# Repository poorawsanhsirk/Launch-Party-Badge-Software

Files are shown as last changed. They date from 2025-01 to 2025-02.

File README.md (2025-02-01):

# Firefly Badge Software Repository

## Overview
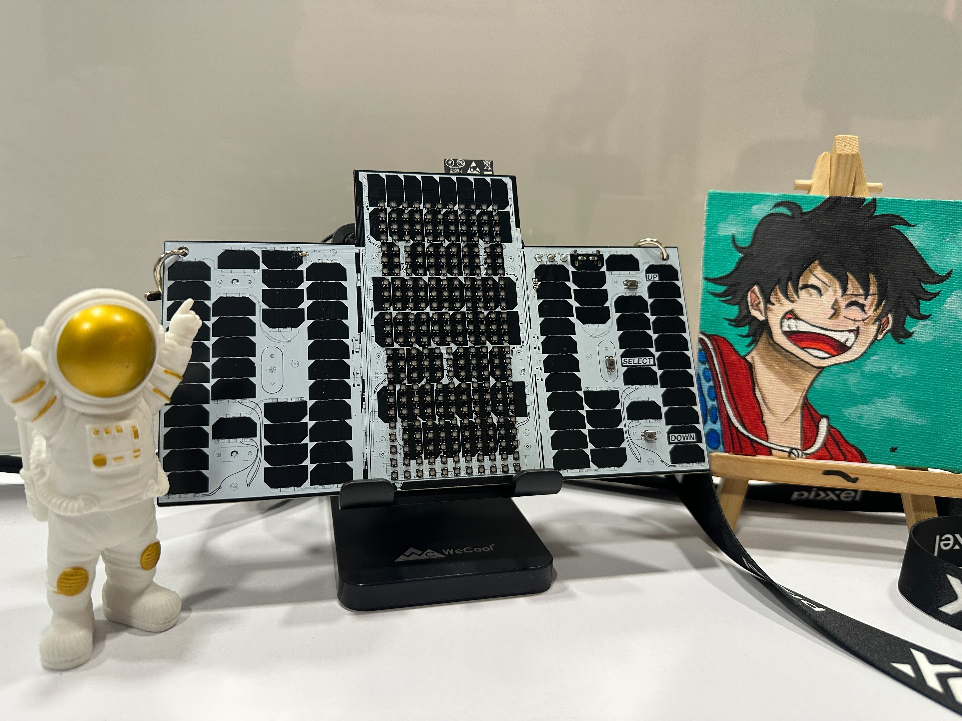
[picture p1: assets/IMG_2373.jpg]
Badge_Picture
  
This Firefly Badge features an **11x24 LED Matrix** that provides a visual representation of various countdown timers for tracking Launch and Injection Time. The matrix uses color-coded animations and progress indicators to signal important milestones.  
The software provided in the repository is meant for the Launch Viewing Party being held at Pixxel Space India Office in HBR Layout, Bangalore.  
The badge has been built to act as a souvenir and memento to celebrate the people, their efforts and the countless sleepless nights that went into making Firefly a reality.

**We highly recommend tinkering around with this badge later**. 
It is basically an ESP32-C3 Devkit with an LED Matrix after you leave the party. Feel free to reach out if you need any help getting started. Looking forward to what people end up building with this.
Psst...Psst, you can build a Firefly Themed Table Clock as a starter project.

---
## Instructions for Programming and developing your own code

1. **Install Arduino IDE on your local machine**
   - Link
2. **Clone this repository on your local machine**
   - If you have Git installed, you can just used `git clone <url>`
   - If you dont have Git install, consider installing Git, it will change your life.
   - If you are still hell-bent on not changing your life, you could just download this repo as a .zip folder and extract it
3. **Navigate to Relevant Folder**
   - After the launch party, the code in release/Version2_LowPower will not work as it requires a connection to Office WiFi and a server to ping.
   - However, you can flash your own code and make the ESP32 do whatever you want. You could re-use the Driver I have written for the LED Matrix Drivers in order to display something
   - If you just want the LEDs to light up and do some fun animations, you could try programming your badge with the `release/Demonstration' firmware
4. Program your badge with the firmware that you want (steps below assume that you want to program the Demonstration code)
   - Connect your badge to your PC/Laptop using a USB-C Cable. This cable provides both power and data connection to the ESP32.
   - Open Arduino IDE and open the Demonstration.ino file by going to File->Open in the IDE Menubar
   - If this is the first time you have installed Arduino IDE, you will have to install the ESP32 Board drivers. Open Board Manager in Arduino IDE and search for ESP32.
   - After installing relevant drivers, your badge will get recognised by the IDE. Please select ESP32C3-Dev Module as your board type and select the correct COM Port
   - Now you are ready to program the badge. Click on the Upload Button in the Arduino IDE. This will compile and flash your badge with the Demonstration Firmware.
5. The Demonstration Firmware does the following animations
   - Blue Progress Bar to simulate Launch Countdown
   - Green LED Flashing
   - Blue LED Flashing
   - Injection Timer Simulation
   - Injection Intimation Simulation
You could cycle through each animation by pressing and holding the UP Button
---
## Installation & Usage
1. **Power ON the Badge**:
   - Connect the provided 9V Battery to the Battery Connector present on the board.
   - Turn ON the board by flipping the Power Switch to the ON Position.
   - Wait a couple of seconds for the ESP32 to fetch relevant information from an API Endpoint hosted locally in Pixxel Office.
   - The **Launch Timer** should start automatically.
2. **Switch to Injection Timer after launch is done**:
   - Press and hold the **Select** button until the blue flashing animation begins.
   - Release the button to transition.
3. **Monitor Progress**:
   - Observe progress bars and flashing indicators to track the timers. Here's to hoping you don't miss watching the Launch :3
4. In order to conserve power and last through the entire launch schedule, the board displays info for 60 seconds and goes to sleep for 20 seconds. Please don't panic if your display goes OFF for a while
---
## LED Matrix Behavior

### 1. **Launch Timer**
- **Initial State**: When the badge is powered ON:
  - Progress towards the **Launch Time** is displayed vertically on the LED Matrix.
  - Each **blue row** represents a step closer to the launch.
- **1 Minute to Launch**:
  - The entire matrix begins flashing **green** to signal the approaching launch time.
- **Post Launch**:
  - The entire matrix glows green.  
---

### 2. **Transition Animation**
- **Activation**:
  - User presses and holds the **Select** button.
- **Animation**:
  - LED Matrix flashes **blue** to confirm the transition. 
- **Completion**:
  - The badge switches between modes once the user releases the button after the blue flashing begins.
---

### 3. **Injection Timer**
- **Initial Display**:
  - The LED Matrix is divided into 3 sections, each **6 rows high**, to display progress for 3 different timers.
  - Progress towards each **Injection Time** is shown by the number of **blue rows lit** in each section.
- **Below 30 Seconds**:
  - The rows corresponding to the timer with less than 30 seconds start flashing **green**.

---

## Technical Details

### LED Matrix
- **Resolution**: 11 columns x 24 rows. 264 RGB LEDs driven by 4 LP5860 LED Matrix Drivers.
- LED Driver ICs are connected over I2C. VIO_EN and VSYNC are also connected  
### Controller 
- **ESP32-C3-WROOM-02-N4 Module**

### Secret Peripheral
- The PCB has provision for an un-populated component which unlocks a lot more projects that you can do with this badge. Maybe even "Attitude Control" your Firefly :)
### Hardware Design
Refer to the hardware directory for KiCAD Files of the Firefly Badge PCB. The repo contains final schematics, layout, gerbers and BoM. Reach out if you need any clarifications.  

Basically everything you require to make your own Firefly Badge in case you missed out on getting your hands on one from the Launch Event

---

## Troubleshooting
This badge was made in 15 days from when we decided to do it. The software for this was written in 48 hours by an Electronics Engineer with no sleep.  
Excuse the bad coding practices.  
Also, there might be some issues when there are around 200 devices in the wild suddenly with close to zero testing.

---

## Glam Shots
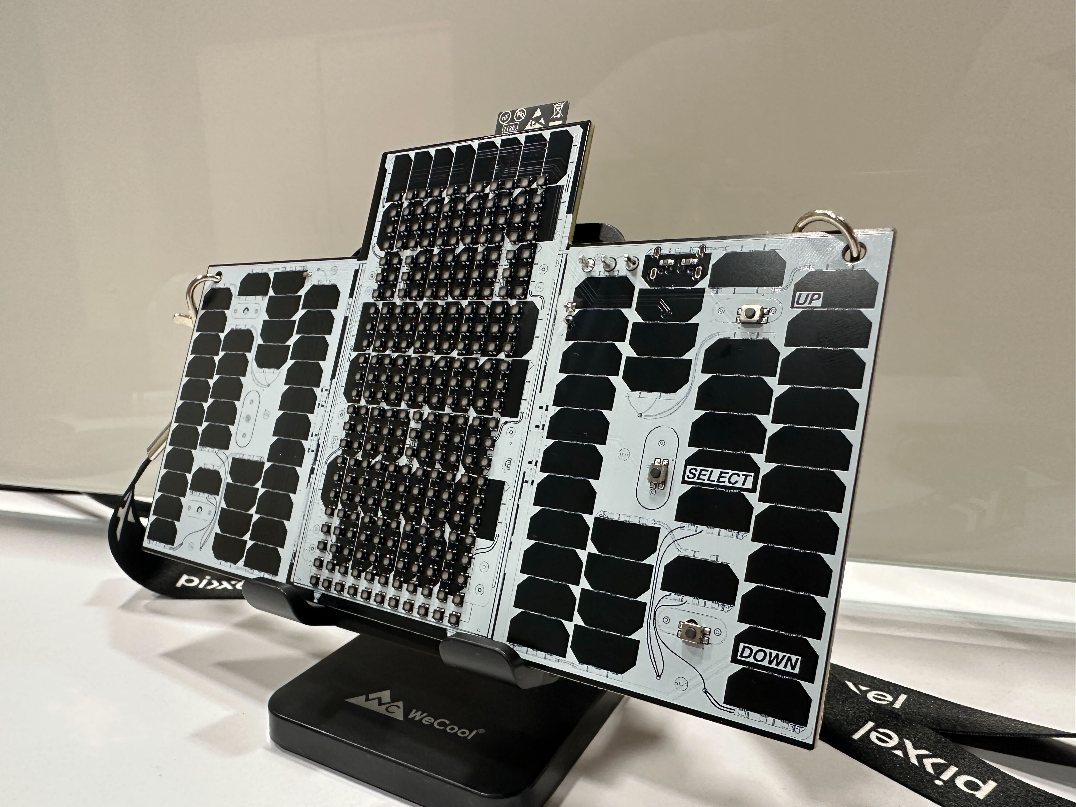
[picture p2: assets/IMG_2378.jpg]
Front

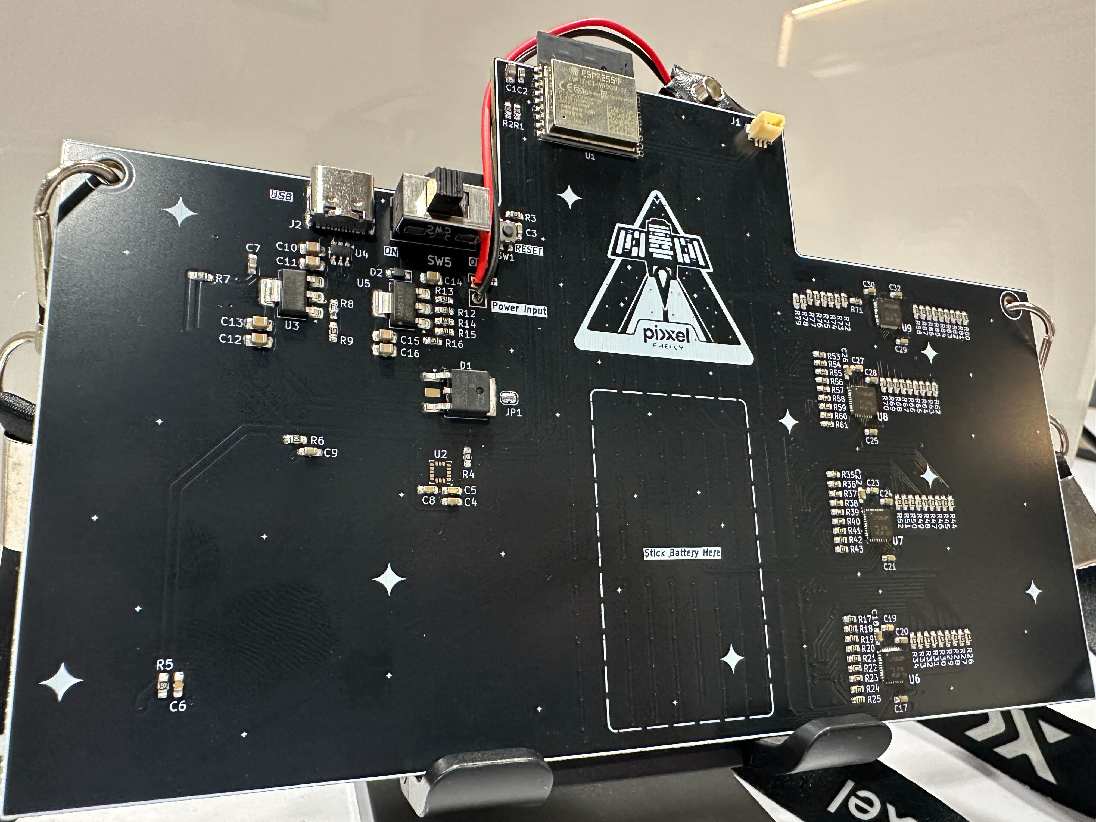
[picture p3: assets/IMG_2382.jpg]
Back

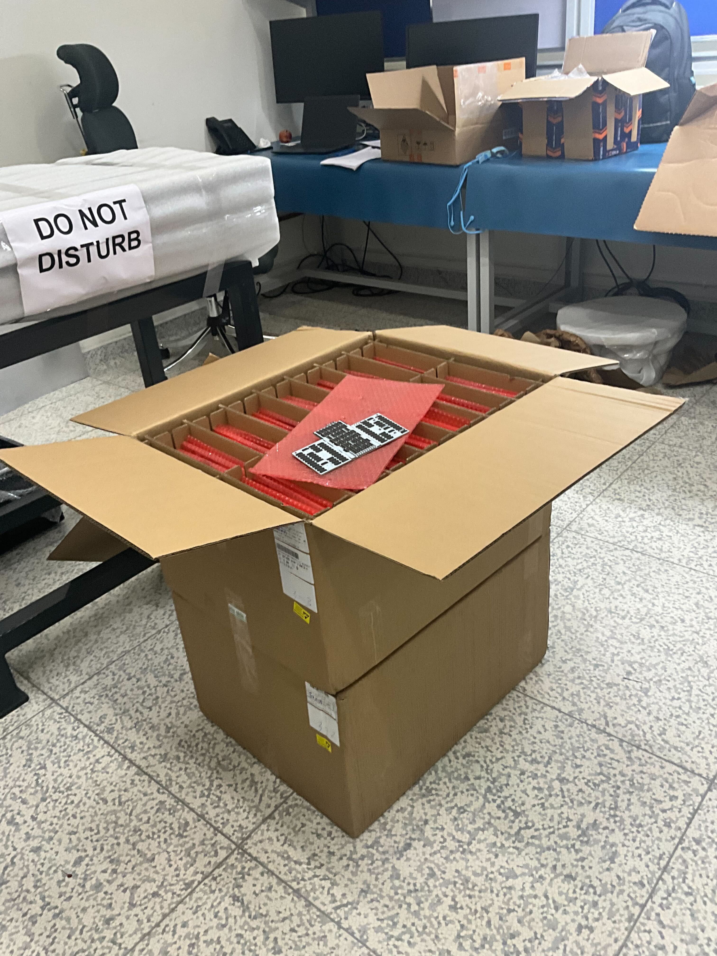
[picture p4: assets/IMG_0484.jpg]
Delivery Box

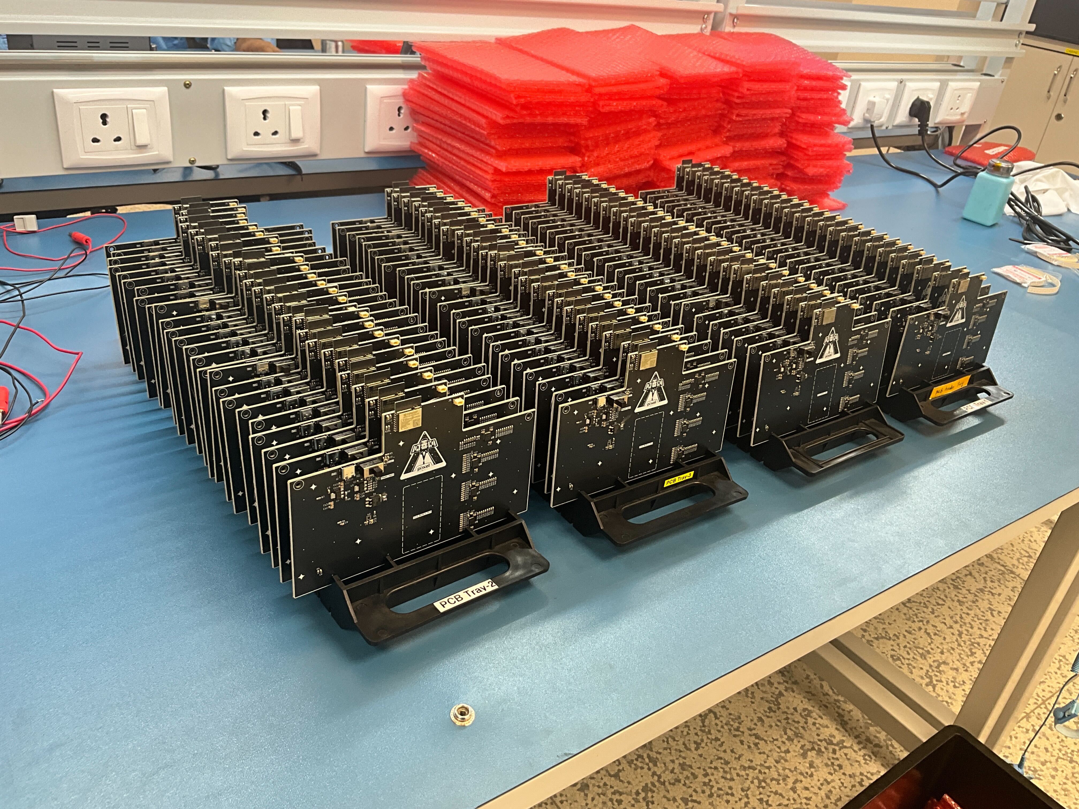
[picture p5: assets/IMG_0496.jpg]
PCB Array

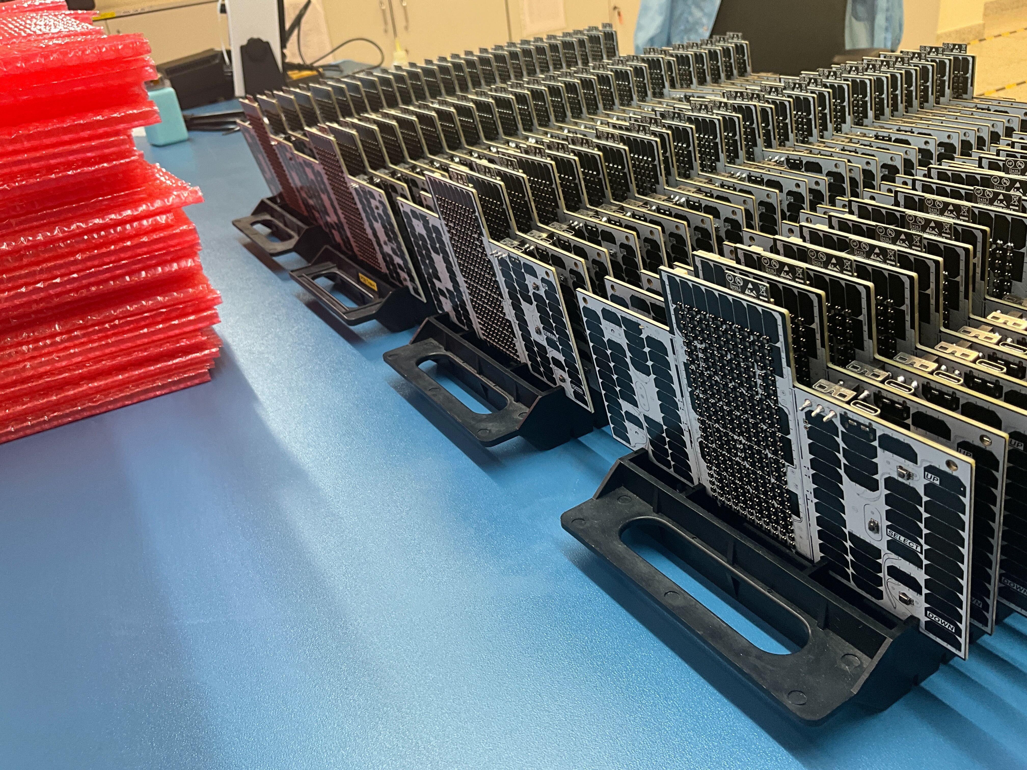
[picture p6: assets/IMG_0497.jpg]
PCB Array1

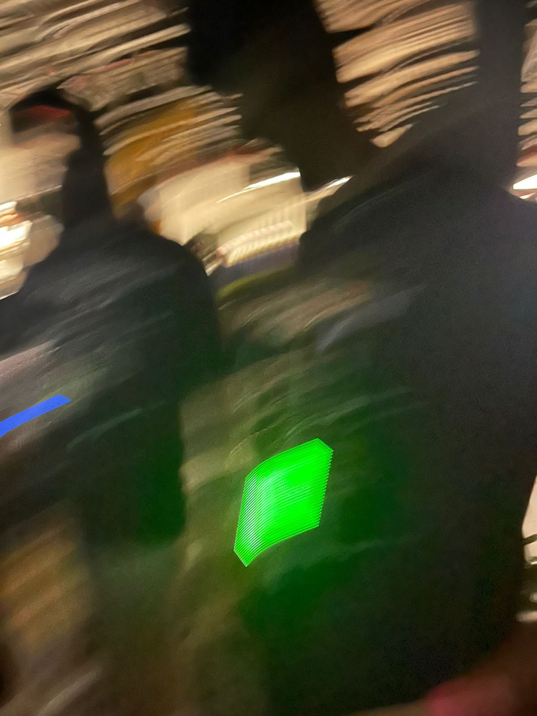
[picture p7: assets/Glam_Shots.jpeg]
Glam Shot

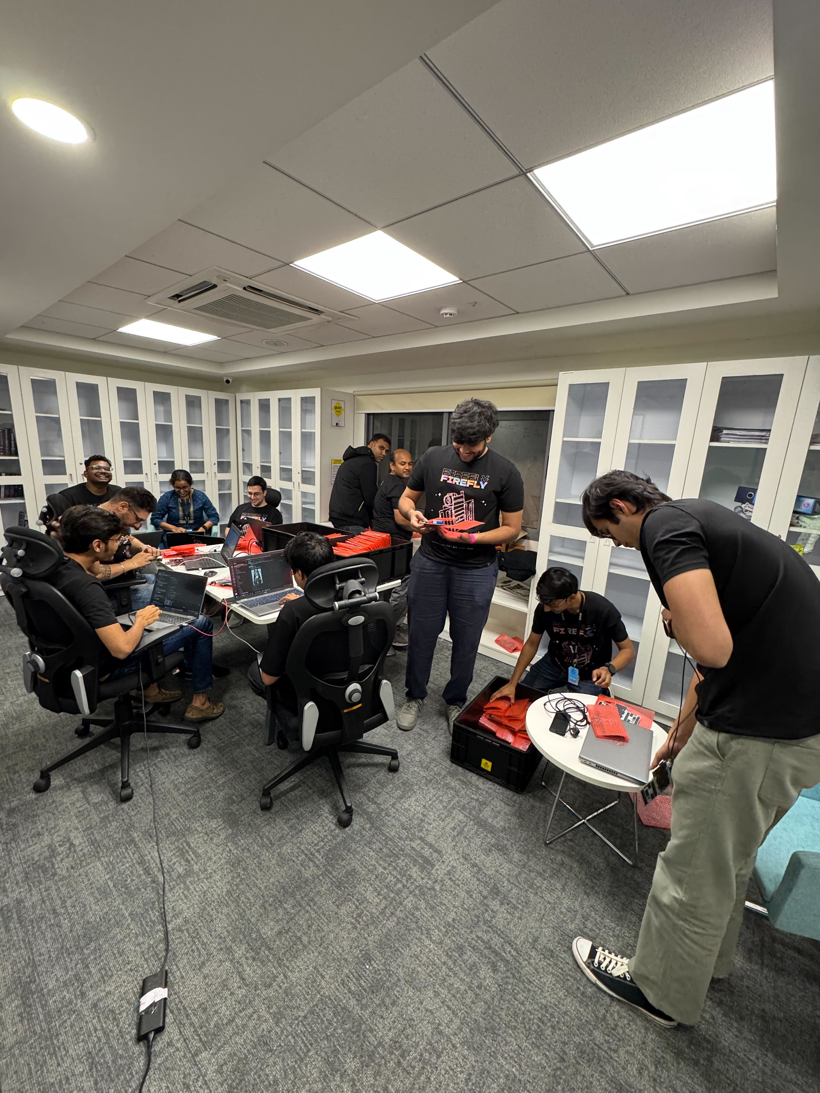
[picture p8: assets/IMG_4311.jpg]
SweatShop Scenes


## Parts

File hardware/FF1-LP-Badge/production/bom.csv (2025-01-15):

Designator | Footprint | Quantity | Value | LCSC Part #
C1, C10, C11, C12, C13, C14, C15, C16 | 0805 | 8 | 10uF_16V_0805
C17, C18, C2, C20, C21, C22, C24, C25, C26, C28, C29, C3, C30, C32, C4, C6, C7, C8, C9 | 0603 | 19 | 1uF_16V_0603
C19, C23, C27, C31, C5 | 0603 | 5 | 1nF_16V_0603
D1 | TO-252-3_TabPin2 | 1 | MBR1045CS | C2898534
D10, D100, D101, D102, D103, D104, D105, D106, D107, D108, D109, D11, D110, D111, D112, D113, D114, D115, D116, D117, D118, D119, D12, D120, D121, D122, D123, D124, D125, D126, D127, D128, D129, D13, D130, D131, D132, D133, D134, D135, D136, D137, D138, D139, D14, D140, D141, D142, D143, D144, D145, D146, D147, D148, D149, D15, D150, D151, D152, D153, D154, D155, D156, D157, D158, D159, D16, D160, D161, D162, D163, D164, D165, D166, D167, D168, D169, D17, D170, D171, D172, D173, D174, D175, D176, D177, D178, D179, D18, D180, D181, D182, D183, D184, D185, D186, D187, D188, D189, D19, D190, D191, D192, D193, D194, D195, D196, D197, D198, D199, D20, D200, D201, D202, D203, D204, D205, D206, D207, D208, D209, D21, D210, D211, D212, D213, D214, D215, D216, D217, D218, D219, D22, D220, D221, D222, D223, D224, D225, D226, D227, D228, D229, D23, D230, D231, D232, D233, D234, D235, D236, D237, D238, D239, D24, D240, D241, D242, D243, D244, D245, D246, D247, D248, D249, D25, D250, D251, D252, D253, D254, D255, D256, D257, D258, D259, D26, D260, D261, D262, D263, D264, D265, D266, D27, D28, D29, D3, D30, D31, D32, D33, D34, D35, D36, D37, D38, D39, D4, D40 | NHB2020RGBAHF | 200 | LED_RBAG | C2874116
D2 | D_SOD-323_HandSoldering | 1 | BZT52C10S | C571388
D41, D42, D43, D44, D45, D46, D47, D48, D49, D5, D50, D51, D52, D53, D54, D55, D56, D57, D58, D59, D6, D60, D61, D62, D63, D64, D65, D66, D67, D68, D69, D7, D70, D71, D72, D73, D74, D75, D76, D77, D78, D79, D8, D80, D81, D82, D83, D84, D85, D86, D87, D88, D89, D9, D90, D91, D92, D93, D94, D95, D96, D97, D98, D99 | NHB2020RGBAHF | 64 | LED_RBAG | C2874116
J1 | BM03BSRSSTB | 1 | BM03B-SRSS-TB | C160389
J2 | USB_C_Receptacle_GCT_USB4105-xx-A_16P_TopMnt_Horizontal | 1 | USB_C_Receptacle_USB2.0_16P | C709357
JP1 | SolderJumper-2_P1.3mm_Bridged2Bar_RoundedPad1.0x1.5mm | 1 | SolderJumper_2_Open
R1, R10, R11, R14, R16, R2, R3, R4, R5, R6, R7, R9 | 0603 | 12 | 5.1k_0.1W_0603
R12, R13, R15, R8 | 0603 | 4 | 3.3k_0.1W_0603
R17, R18, R19, R20, R21, R22, R23, R24, R25, R26, R27, R28, R29, R30, R31, R32, R33, R34, R35, R36, R37, R38, R39, R40, R41, R42, R43, R44, R45, R46, R47, R48, R49, R50, R51, R52, R53, R54, R55, R56, R57, R58, R59, R60, R61, R62, R63, R64, R65, R66, R67, R68, R69, R70, R71, R72, R73, R74, R75, R76, R77, R78, R79, R80, R81, R82, R83, R84, R85, R86, R87, R88 | 0603 | 72 | 100R_0.1W_0603
SW1, SW2, SW3, SW4 | Button-TSA008A187 | 4 | SW_Push | C2888423
SW5 | SS12D10L5 | 1 | SS-12D10L5 | C319012
U1 | ESP32-C3-WROOM-02 | 1 | ESP32-C3-WROOM-02 | C2934560
U2 | LGA-16_3x3mm_P0.5mm_LayoutBorder3x5y | 1 | ICM-20602 | C97633
U3, U5 | SOT-223-3_TabPin2 | 2 | AMS1117 | C347224
U4 | SOT-23-6 | 1 | USBLC6-2SC6 | C7519
U6, U7, U8, U9 | QFN40P500X500X100-41N-D | 4 | PLP5860RKPR

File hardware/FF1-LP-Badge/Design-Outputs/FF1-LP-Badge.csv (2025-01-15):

Reference | Value | Manufacturer Part Number | Price | Qty | Vendor Part Number | Manufacturer | Datasheet | Footprint | DNP
BT1 | Battery |  | 0.5 | 1 |  |  | ~ | Battery:BatteryHolder_Keystone_2462_2xAA
C1,C3,C11,C12,C14,C15,C16,C18,C19,C20,C22,C23,C24,C26 | 1uF_16V_0603 |  |  | 14 |  |  | ~ | Capacitor_SMD:C_0603_1608Metric_Pad1.08x0.95mm_HandSolder
C2 | 0.1uF_16V_0603 |  |  | 1 |  |  | ~ | Capacitor_SMD:C_0603_1608Metric_Pad1.08x0.95mm_HandSolder
C4,C5,C6,C7,C8,C9,C10 | 10uF_16V_0805 |  |  | 7 |  |  | ~ | Capacitor_SMD:C_0805_2012Metric_Pad1.18x1.45mm_HandSolder
C13,C17,C21,C25 | 1nF_16V_0603 |  |  | 4 |  |  | ~ | Capacitor_SMD:C_0603_1608Metric_Pad1.08x0.95mm_HandSolder
D1,D2 | SL02-GS08 | SL02-GS08 | 0.0451 | 2 | C7422632 | FUXINSEMI | https://www.lcsc.com/datasheet/lcsc_datasheet_2306151008_FUXINSEMI-SL02-GS08_C7422632.pdf | Diode_SMD:D_SOD-123
D3,D4,D5,D6,D7,D8,D9,D10,D11,D12,D13,D14,D15,D16,D17,D18,D19,D20,D21,D22,D23,D24,D25,D26,D27,D28,D29,D30,D31,D32,D33,D34,D35,D36,D37,D38,D39,D40,D41,D42,D43,D44,D45,D46,D47,D48,D49,D50,D51,D52,D53,D54,D55,D56,D57,D58,D59,D60,D61,D62,D63,D64,D65,D66,D67,D68,D69,D70,D71,D72,D73,D74,D75,D76,D77,D78,D79,D80,D81,D82,D83,D84,D85,D86,D87,D88,D89,D90,D91,D92,D93,D94,D95,D96,D97,D98,D99,D100,D101,D102,D103,D104,D105,D106,D107,D108,D109,D110,D111,D112,D113,D114,D115,D116,D117,D118,D119,D120,D121,D122,D123,D124,D125,D126,D127,D128,D129,D130,D131,D132,D133,D134,D135,D136,D137,D138,D139,D140,D141,D142,D143,D144,D145,D146,D147,D148,D149,D150,D151,D152,D153,D154,D155,D156,D157,D158,D159,D160,D161,D162,D163,D164,D165,D166,D167,D168,D169,D170,D171,D172,D173,D174,D175,D176,D177,D178,D179,D180,D181,D182,D183,D184,D185,D186,D187,D188,D189,D190,D191,D192,D193,D194,D195,D196,D197,D198,D199,D200,D201,D202,D203,D204,D205,D206,D207,D208,D209,D210,D211,D212,D213,D214,D215,D216,D217,D218,D219,D220,D221,D222,D223,D224,D225,D226,D227,D228,D229,D230,D231,D232,D233,D234,D235,D236,D237,D238,D239,D240,D241,D242,D243,D244,D245,D246,D247,D248,D249,D250,D251,D252,D253,D254,D255,D256,D257,D258,D259,D260,D261,D262,D263,D264,D265,D266 | LED_RBAG | NH-B2020RGBA-HF | 0.0042 | 264 | C2874116 | Foshan NationStar Optoelectronics | https://www.lcsc.com/datasheet/lcsc_datasheet_2108150330_Foshan-NationStar-Optoelectronics-NH-B2020RGBA-HF_C2874116.pdf | Footprints:NHB2020RGBAHF
J1 | BM03B-SRSS-TB | BM03B-SRSS-TB(LF)(SN) | 0.1209 | 1 | C160389 | JST | https://datasheet.datasheetarchive.com/originals/dk/DKDS-2/32971.pdf | Footprints:BM03BSRSSTB
J2 | Conn_01x02_Pin |  |  | 1 |  |  | ~ | Connector_PinSocket_2.54mm:PinSocket_1x02_P2.54mm_Vertical
J3 | USB_C_Receptacle_USB2.0_16P | KH-TYPE-C-16P | 0.0453 | 1 | C709357 | Shenzhen Kinghelm Elec | https://www.lcsc.com/datasheet/lcsc_datasheet_2404191039_Shenzhen-Kinghelm-Elec-KH-TYPE-C-16P_C709357.pdf | Connector_USB:USB_C_Receptacle_GCT_USB4105-xx-A_16P_TopMnt_Horizontal
L1 | 10uH_2A | SL0420-100M | 0.0726 | 1 | C22463809 | TECHFUSE | https://www.lcsc.com/datasheet/lcsc_datasheet_2406141138_TECHFUSE-SL0420-100M_C22463809.pdf | Footprints:SL0420-100M
R1,R2,R3,R4,R5,R6,R8,R9 | 5.1k_0.1W_0603 |  |  | 8 |  |  | ~ | Resistor_SMD:R_0603_1608Metric_Pad0.98x0.95mm_HandSolder
R7,R11 | 7.5k_0.1W_0603 |  |  | 2 |  |  | ~ | Resistor_SMD:R_0603_1608Metric_Pad0.98x0.95mm_HandSolder
R10 | 1k_0.1W_0603 |  |  | 1 |  |  | ~ | Resistor_SMD:R_0603_1608Metric_Pad0.98x0.95mm_HandSolder
R12,R13,R14,R15,R16,R17,R18,R19,R20,R21,R22,R23,R24,R25,R26,R27,R28,R29,R30,R31,R32,R33,R34,R35,R36,R37,R38,R39,R40,R41,R42,R43,R44,R45,R46,R47,R48,R49,R50,R51,R52,R53,R54,R55,R56,R57,R58,R59,R60,R61,R62,R63,R64,R65,R66,R67,R68,R69,R70,R71,R72,R73,R74,R75,R76,R77,R78,R79,R80,R81,R82,R83 | 100R_0.1W_0603 |  |  | 72 |  |  | ~ | Resistor_SMD:R_0603_1608Metric_Pad0.98x0.95mm_HandSolder
SW1 | SW_Push | TSA008A18726A07 |  | 1 | C2888423 | BZCN | https://www.lcsc.com/datasheet/lcsc_datasheet_2410010002_BZCN-TSA008A18726A07_C2888423.pdf | Footprints:Button-TSA008A187
SW2 | SS-12D10L5 | SS-12D10L5 | 0.1825 | 1 | C319012 | XKB Connectivity | http://www.helloxkb.com/public/images/pdf/SS-12D10XXX.pdf | Footprints:SS12D10L5
U1 | ESP32-C3-WROOM-02 | ESP32-C3-WROOM-02-N4 | 2.8197 | 1 | C2934560 | Espressif Systems | https://www.espressif.com/sites/default/files/documentation/esp32-c3-wroom-02_datasheet_en.pdf | RF_Module:ESP32-C3-WROOM-02
U2 | NCP1117-3.3_SOT223 | NCP1117ST33T3G | 0.2005 | 1 | C26537 | onsemi | http://www.onsemi.com/pub_link/Collateral/NCP1117-D.PDF | Package_TO_SOT_SMD:SOT-223-3_TabPin2
U3 | USBLC6-2SC6 | USBLC6-2SC6 | 0.0707 | 1 | C7519 | STMicroelectronics | https://www.st.com/resource/en/datasheet/usblc6-2.pdf | Package_TO_SOT_SMD:SOT-23-6
U4 | MT3608 | MT3608L | 0.0285 | 1 | C2932326 | XI'AN Aerosemi Tech | https://www.olimex.com/Products/Breadboarding/BB-PWR-3608/resources/MT3608.pdf | Package_TO_SOT_SMD:SOT-23-6
U5 | LMV331 | LMV331TP | 0.0619 | 1 | C41431784 | TECH PUBLIC | https://www.lcsc.com/datasheet/lcsc_datasheet_2410231144_TECH-PUBLIC-LMV331TP_C41431784.pdf | Package_TO_SOT_SMD:SOT-23-5_HandSoldering
U6,U7,U8,U9 | PLP5860RKPR |  | 1.099 | 4 |  |  | https://www.ti.com/lit/ds/symlink/lp5860.pdf?ts=1628151496099 | Footprints:QFN40P500X500X100-41N-D

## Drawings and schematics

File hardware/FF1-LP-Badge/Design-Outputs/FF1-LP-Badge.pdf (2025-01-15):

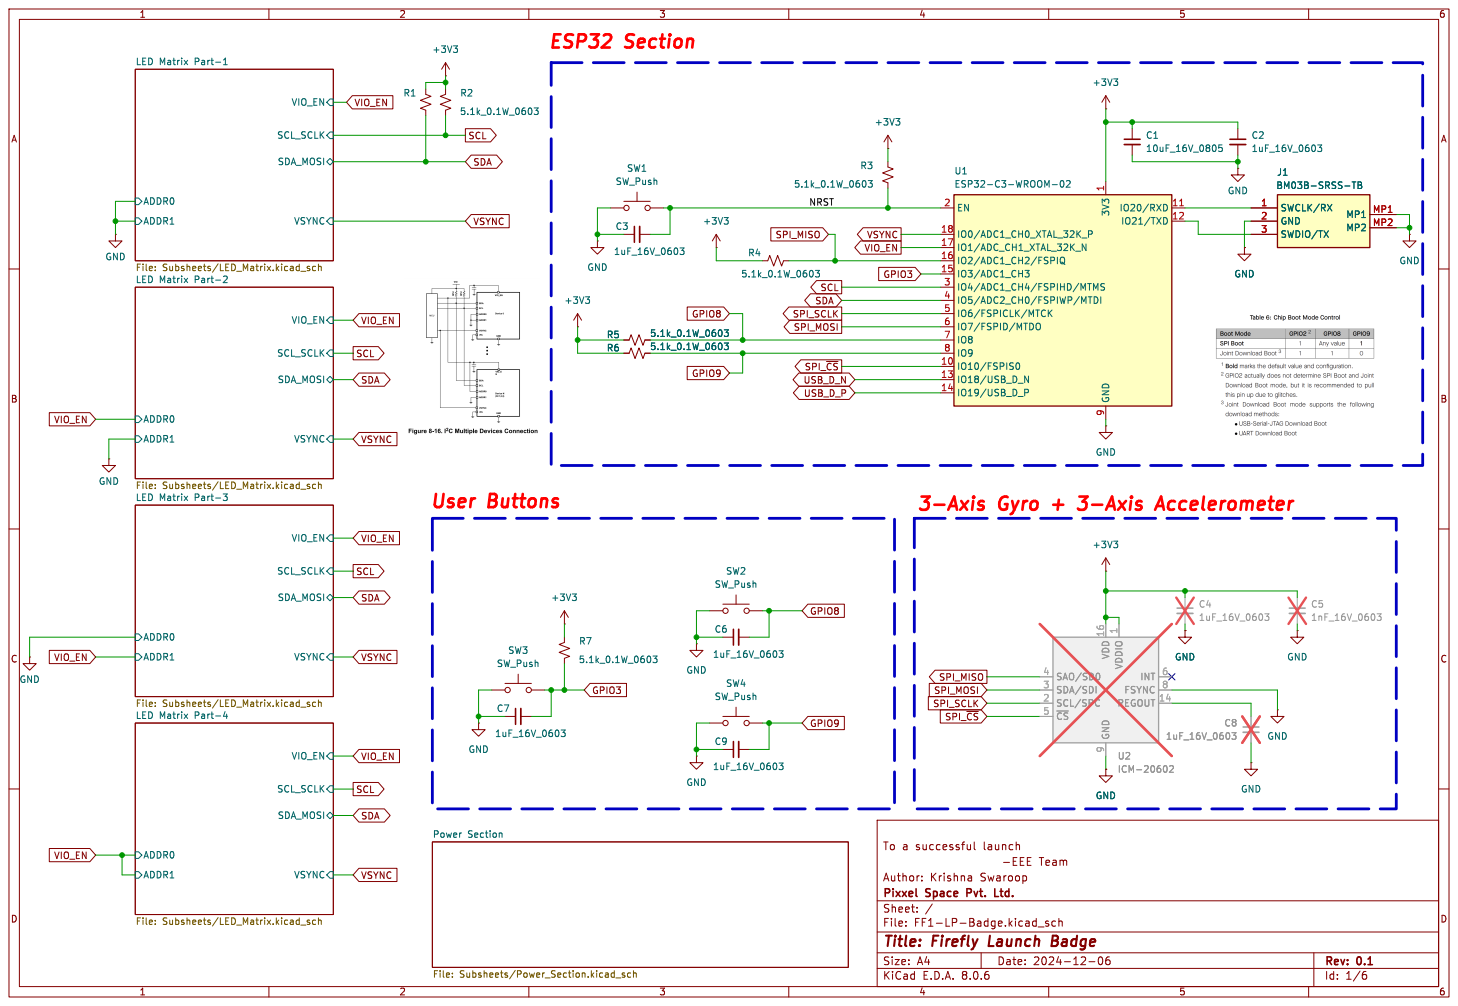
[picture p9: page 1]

LED Matrix Part-2 File: Subsheets/LED_Matrix.kicad_schVSYNC

1 REGOUT 14 VDD 16 SCL/SPC 2 SDA/SDI 3 SAO/SD0 4 ~{CS} 5

LED Matrix Part-4 File: Subsheets/LED_Matrix.kicad_schVSYNC

Id: 1/6 Title: Firefly Launch Badge

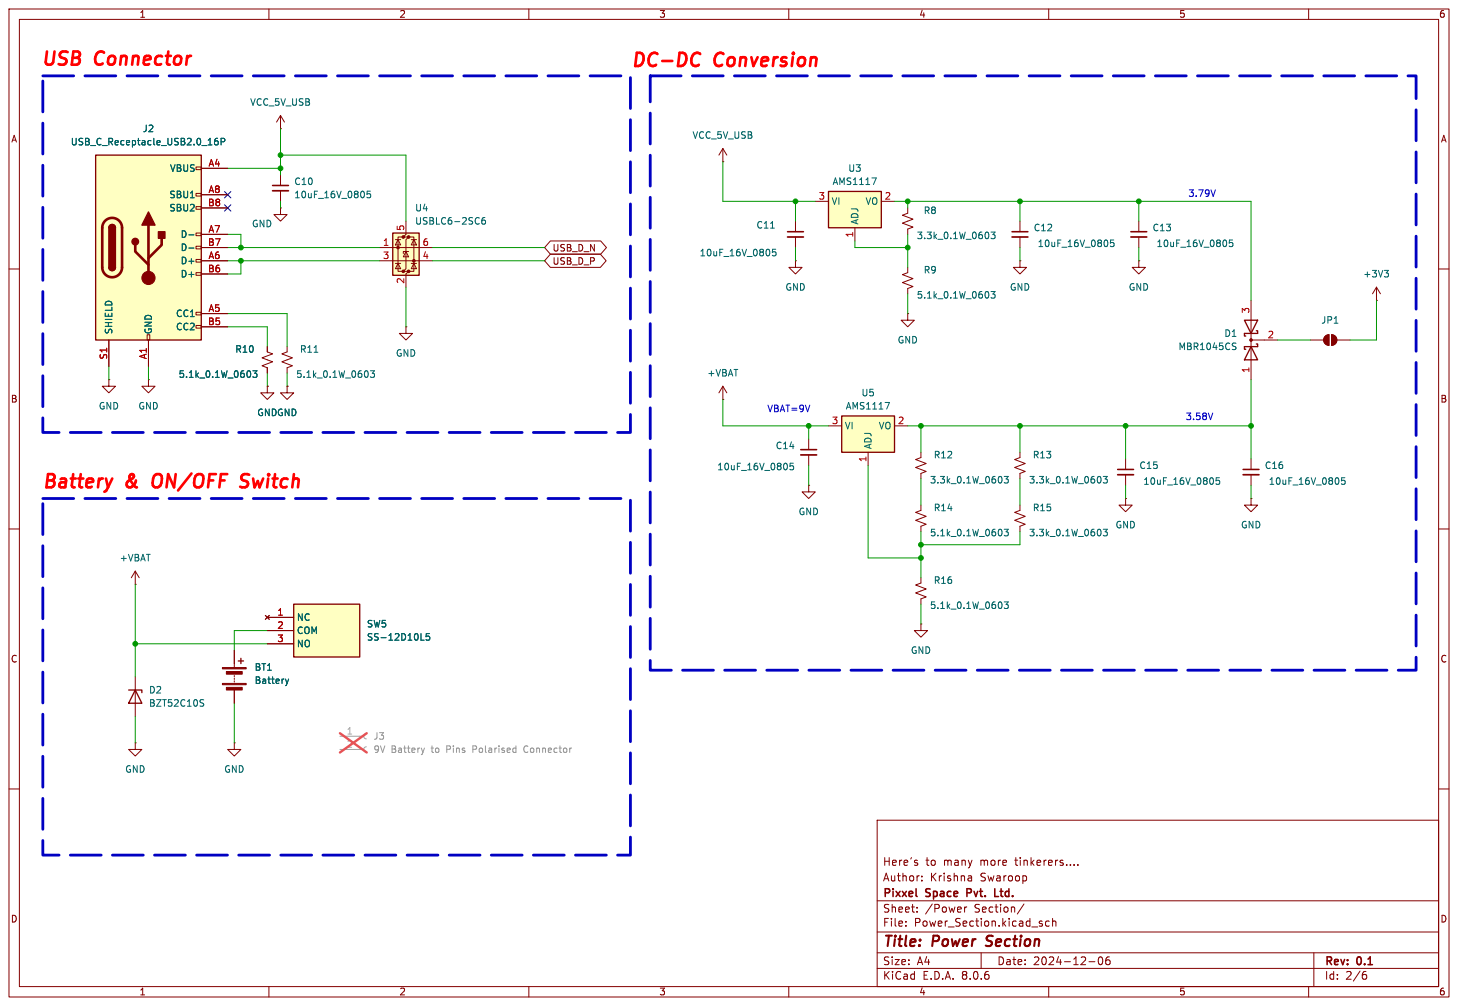
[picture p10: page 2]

Battery & ON/OFF Switch

Id: 2/6 Title: Power Section

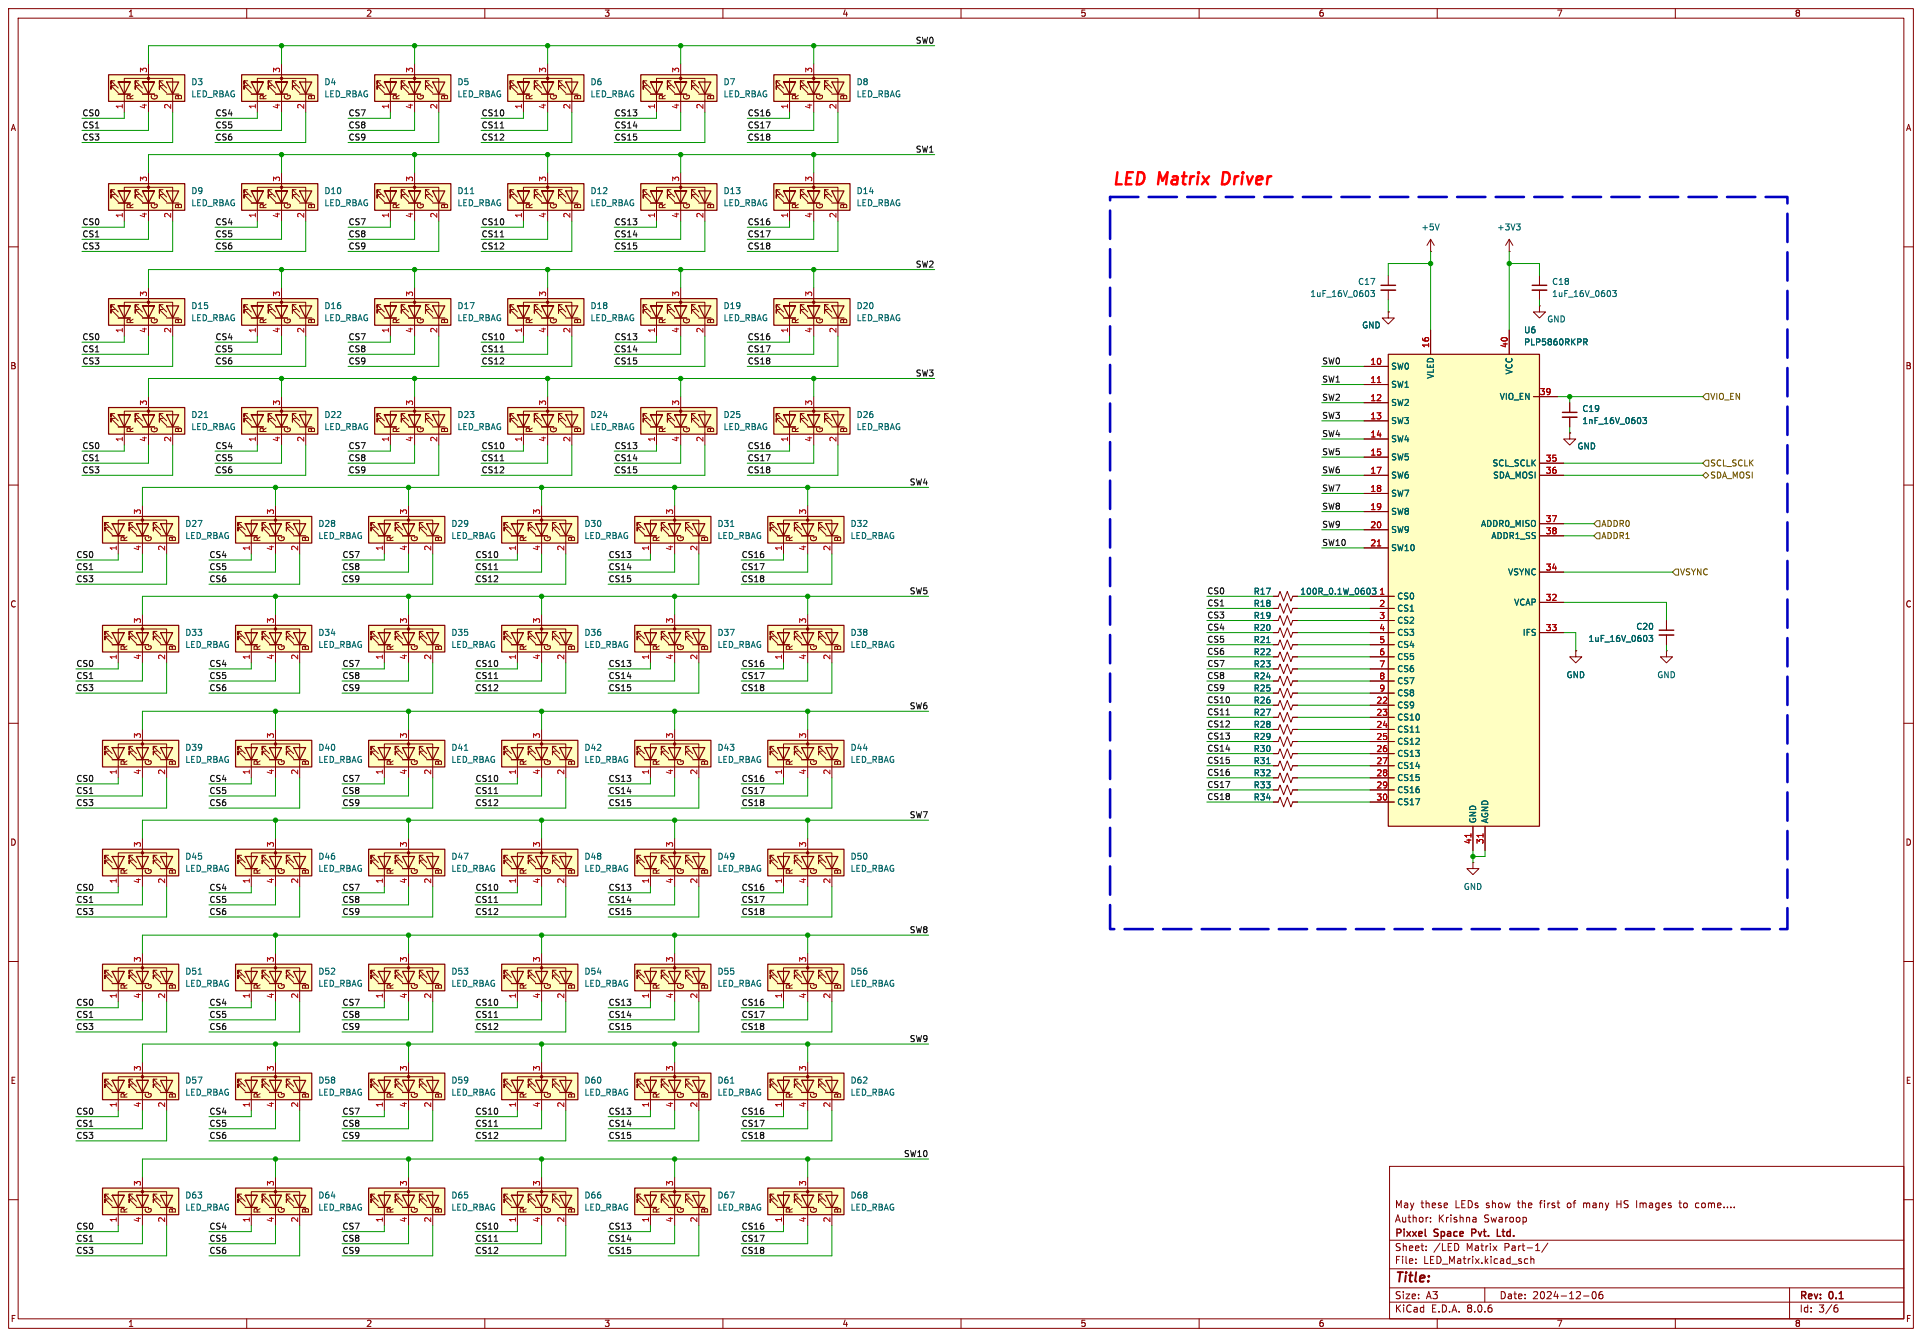
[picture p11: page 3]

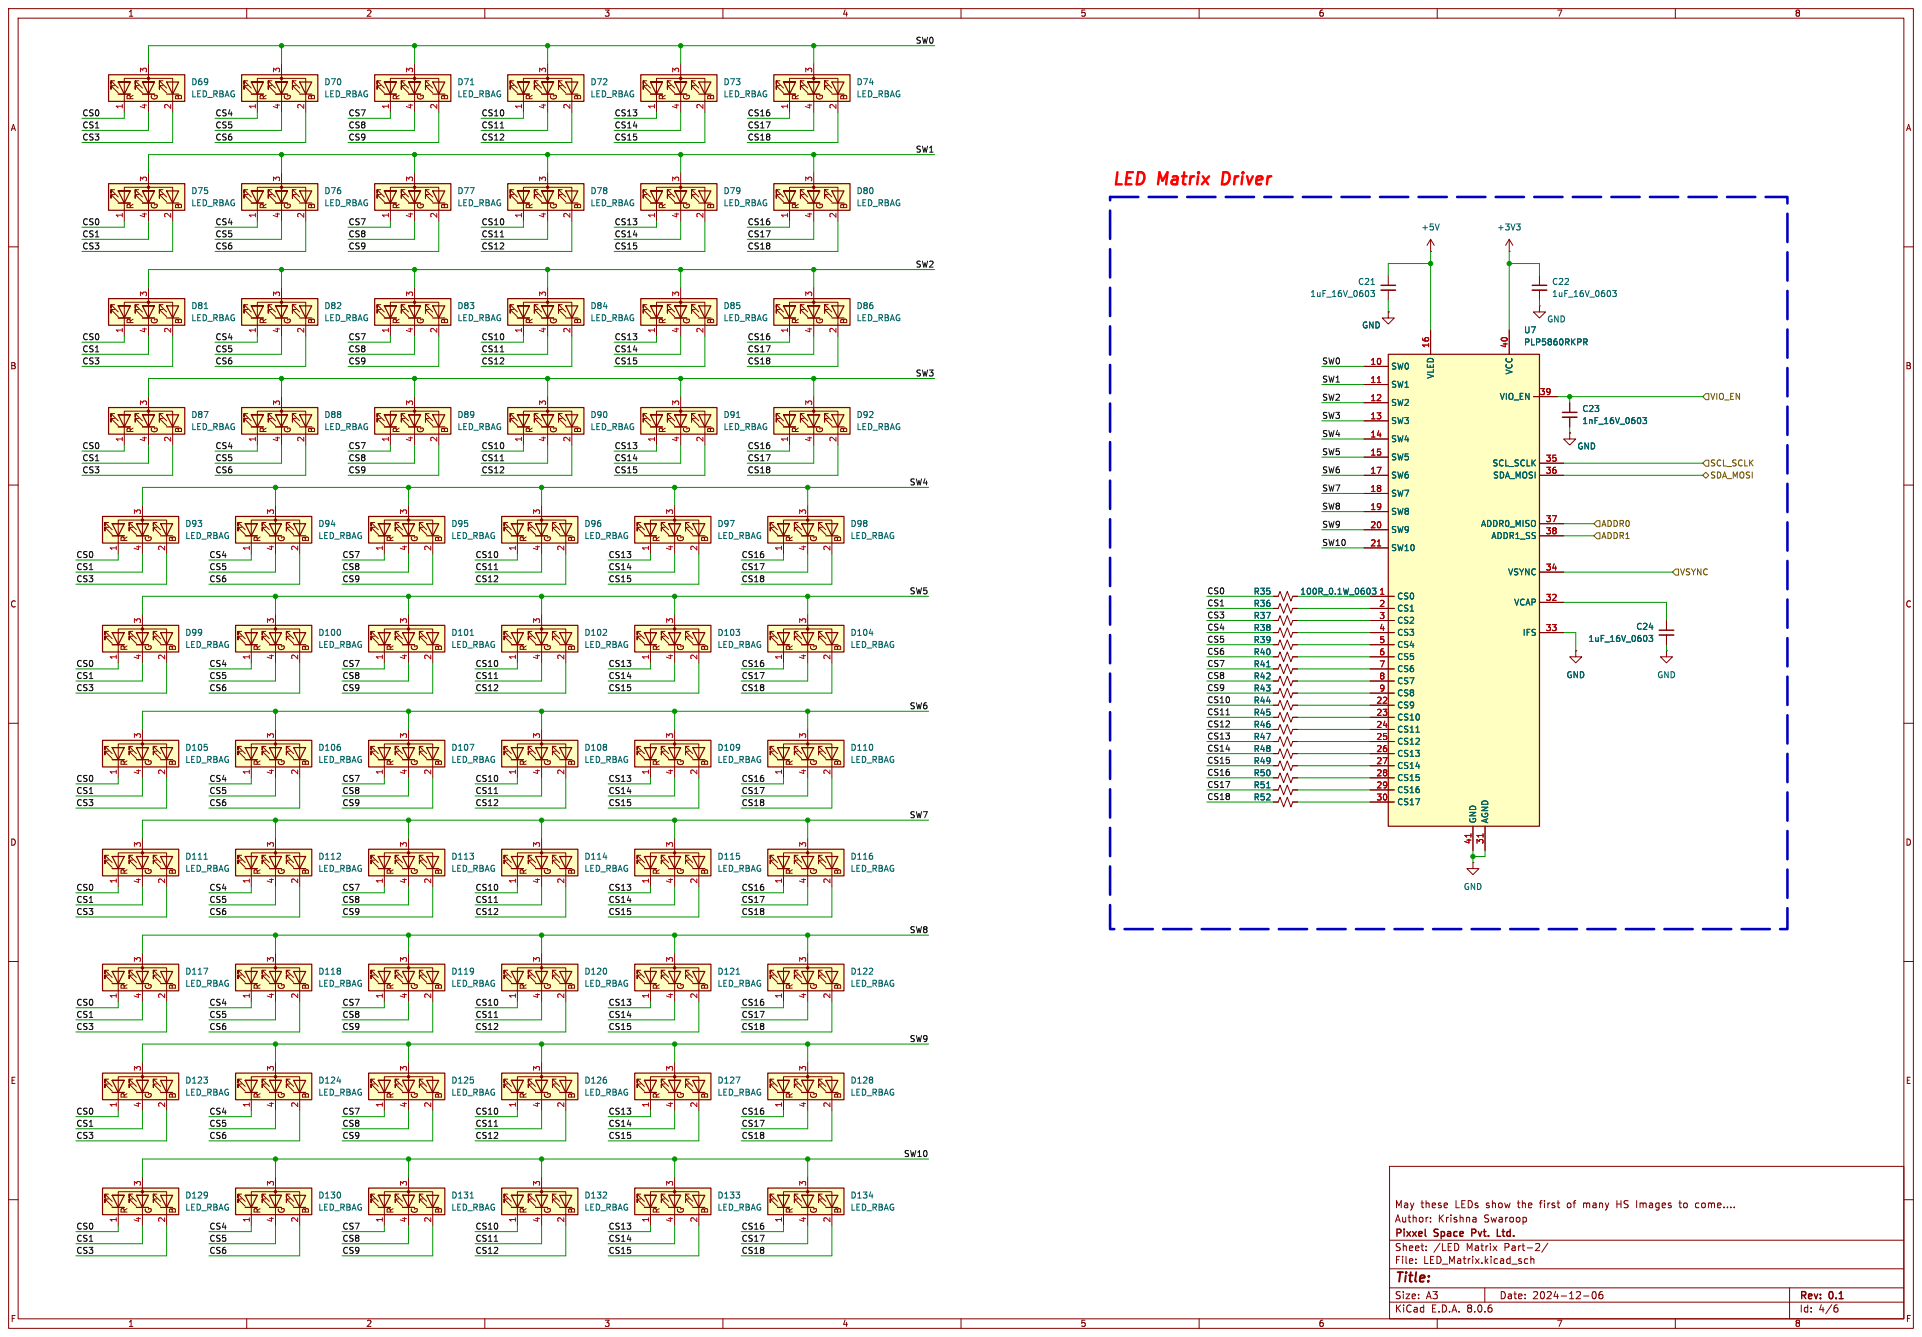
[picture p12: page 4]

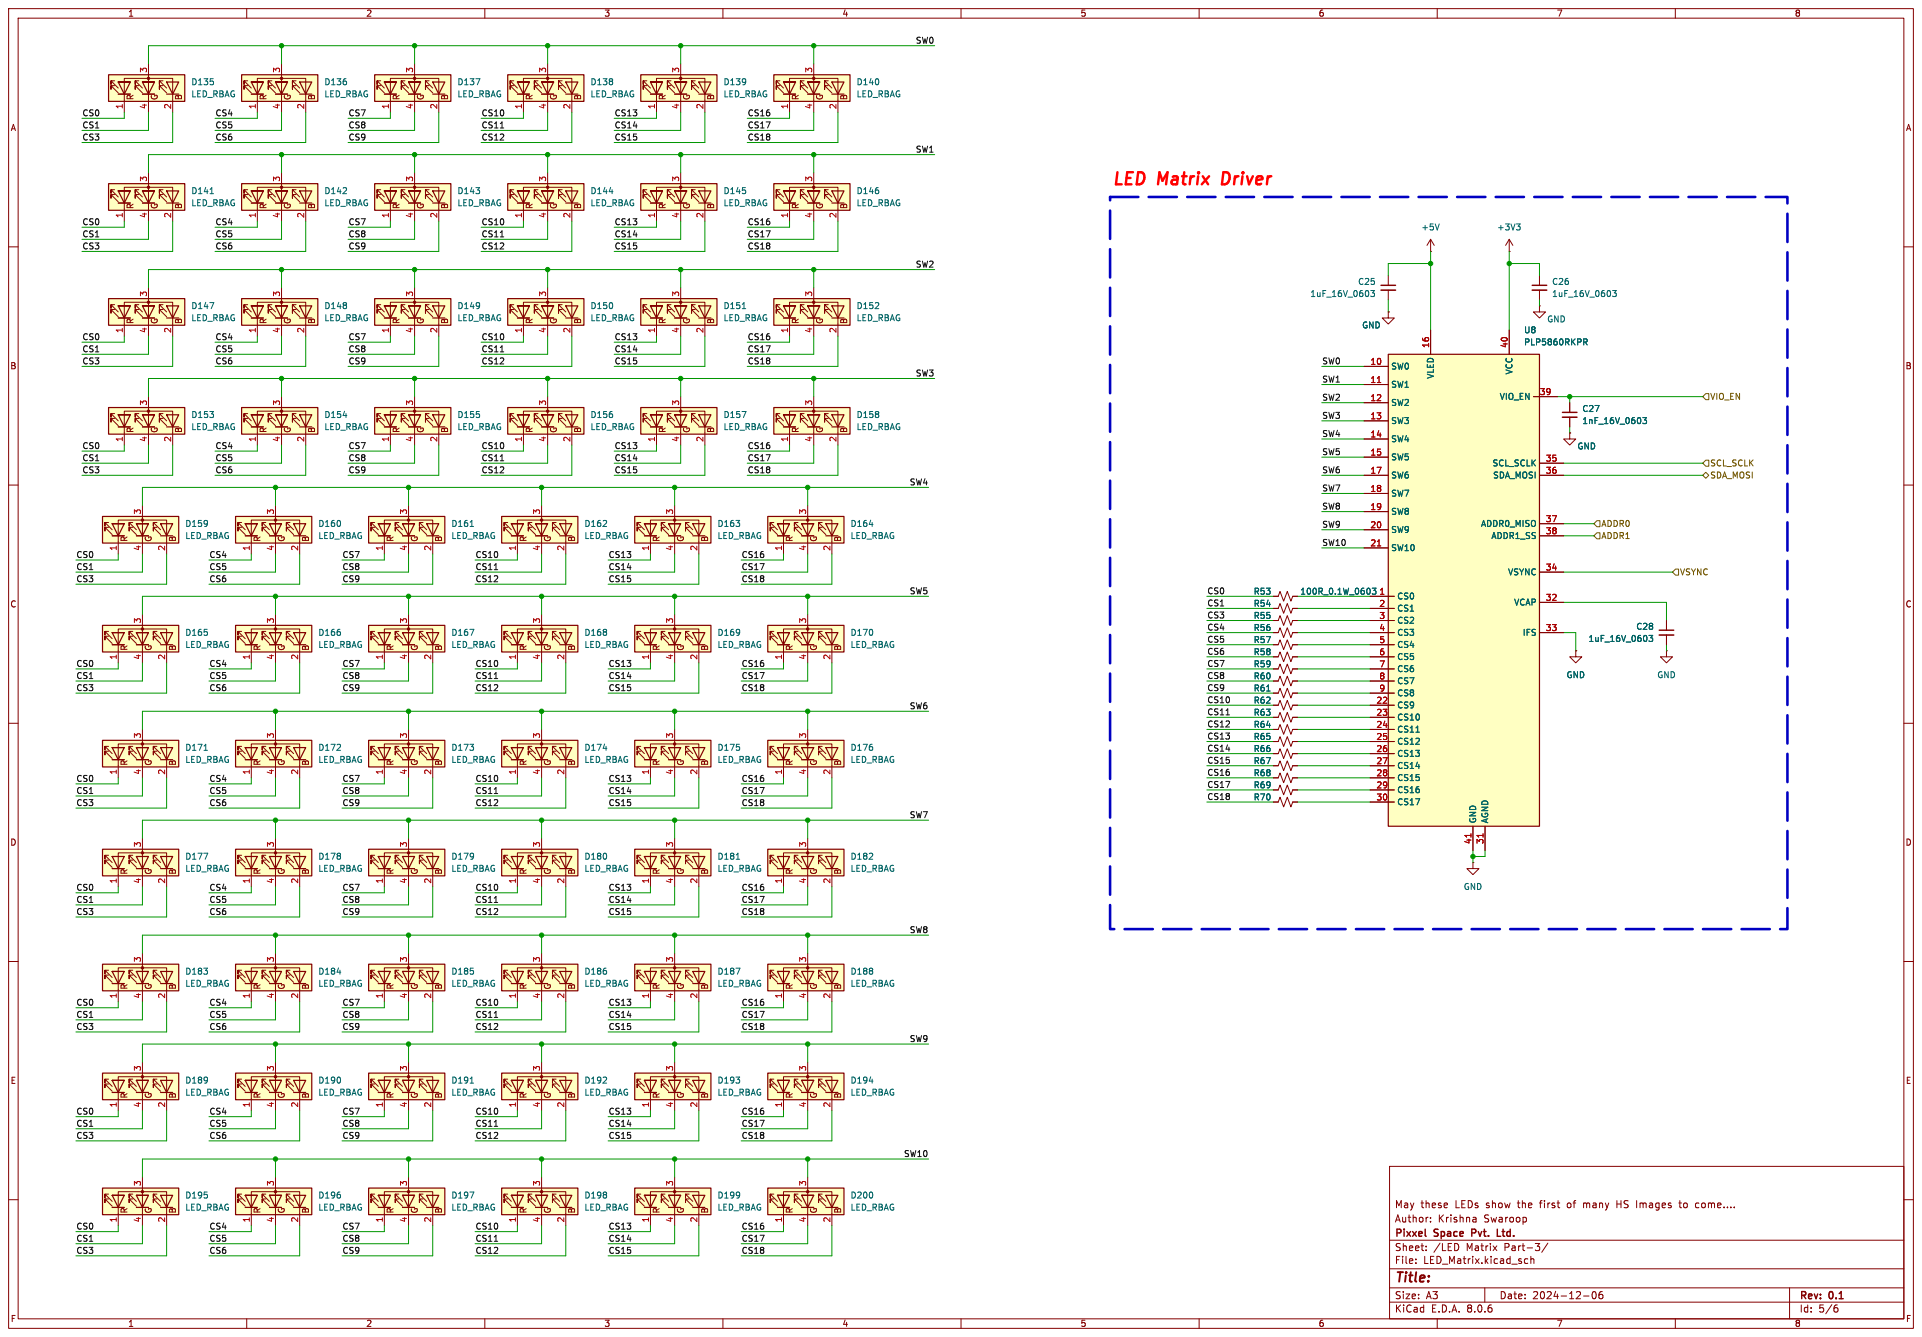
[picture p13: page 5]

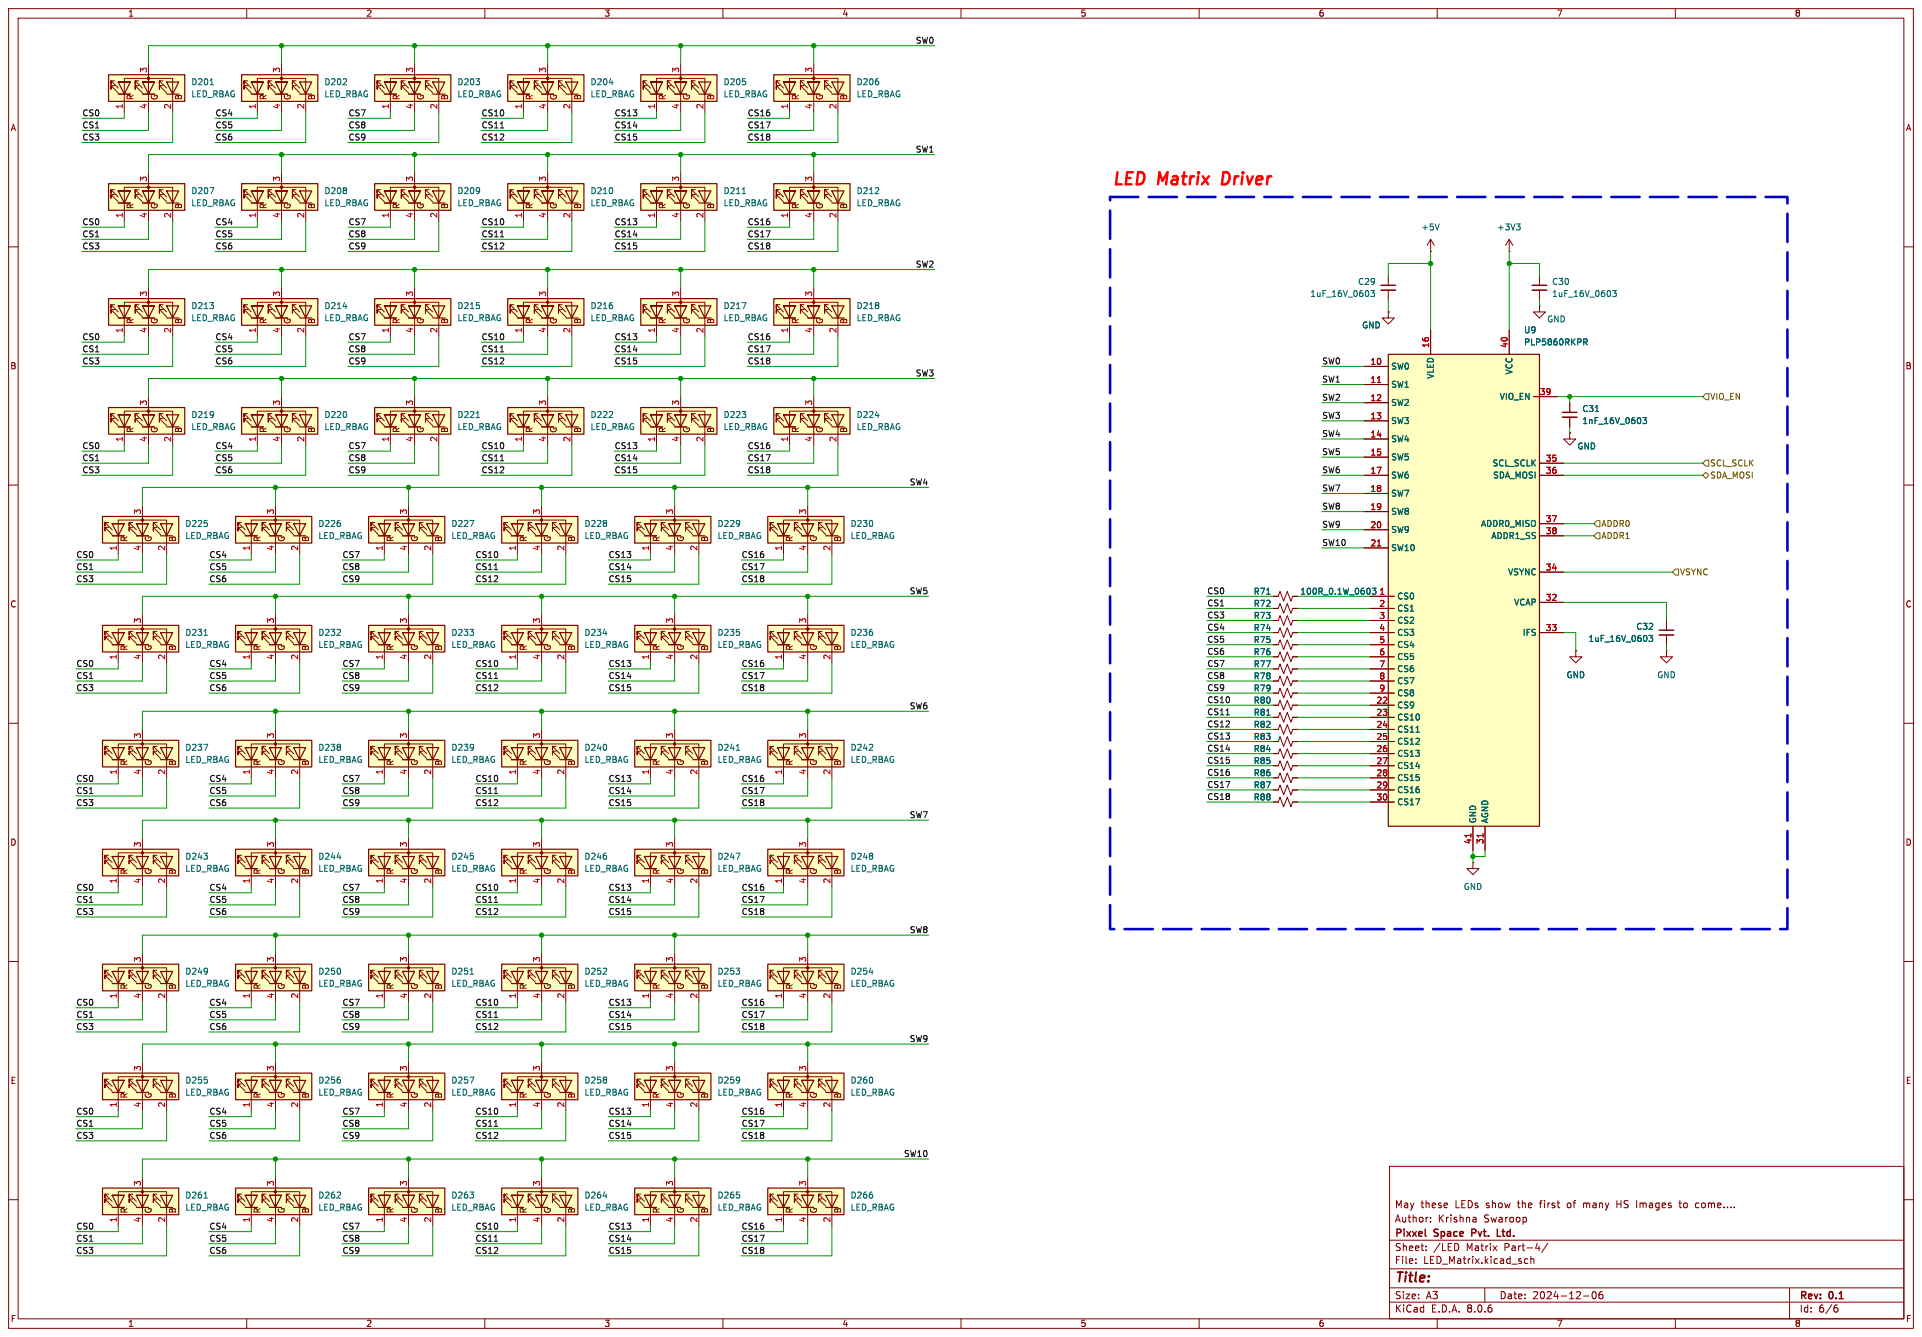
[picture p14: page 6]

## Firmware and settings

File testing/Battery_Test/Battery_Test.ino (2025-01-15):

#include <WiFi.h>
#include <HTTPClient.h>
#include <ArduinoJson.h>


#include "LP586x_I2C.h"
#include <time.h>
// #include "esp32-hal-time.h"

#include "Wire.h"
#include <stdint.h>


#define SLAVE_ADDRESS_1 0x10
#define SLAVE_ADDRESS_2 0x11
#define SLAVE_ADDRESS_3 0x12
#define SLAVE_ADDRESS_4 0x13

#define ENABLE_PIN 0x01
#define SYNC_PIN 0x00

#define sdaPin 0x05
#define sclPin 0x04

#define INTIMATION_TIME 0x3C
#define INJECTION_INTIMATION_TIME 0x20

LP586X_I2C Drivers[] = {
  LP586X_I2C (SLAVE_ADDRESS_1, ENABLE_PIN, SYNC_PIN),
  LP586X_I2C (SLAVE_ADDRESS_2, ENABLE_PIN, SYNC_PIN),
  LP586X_I2C (SLAVE_ADDRESS_3, ENABLE_PIN, SYNC_PIN),
  LP586X_I2C (SLAVE_ADDRESS_4, ENABLE_PIN, SYNC_PIN)
};

// WiFi Credentials
const char* ssid = "Your SSID";
const char* password = "Your Password";

const char* ntpServer = "pool.ntp.org";
const long gmtOffset_sec = 0;    // IST offset: (5 hours * 3600) + (30 minutes * 60) = 19800 seconds
const int daylightOffset_sec = 0;    // India doesn't use DST, so set to 0

const int NTP_UPDATE_INTERVAL = 3600000;  // Update NTP every hour (in milliseconds)
unsigned long lastNTPUpdate = 0;


// API EndPoint Details
const char* apiEndpoint = "ADD API ENDPOINT HERE";
// Target Launch Time (24-hour format)
volatile int LAUNCH_TARGET_HOUR = 0;    // 4:00 AM
volatile int LAUNCH_TARGET_MIN = 0;
volatile int LAUNCH_TARGET_SEC = 0;

// Target Inception Time for FF-1 (24-Hour Format)
volatile int FF1_INJECTION_TARGET_HOUR = 0;
volatile int FF1_INJECTION_TARGET_MIN = 0;
volatile int FF1_INJECTION_TARGET_SEC = 0;

// Target Inception Time for FF-1 (24-Hour Format)
volatile int FF2_INJECTION_TARGET_HOUR = 0;
volatile int FF2_INJECTION_TARGET_MIN = 0;
volatile int FF2_INJECTION_TARGET_SEC = 0;

// Target Inception Time for FF-1 (24-Hour Format)
volatile int FF3_INJECTION_TARGET_HOUR = 0;
volatile int FF3_INJECTION_TARGET_MIN = 0;
volatile int FF3_INJECTION_TARGET_SEC = 0;


// Global time structure
struct tm timeinfo;
// long timeRemainingToLaunch = 0;             
long timeRemainingToLaunchSincePowerON = 0;    // Global Variable to store how much time is remaining to launch
bool eventTransition = 0;
bool Launch_Done = 0;

/**
 * State Manager Global Variables
 */
int menuState;
int previousMenuState;
#define LAUNCH_TIMER 0
#define INJECTION_TIMERS 1
#define TRANSITION 2
#define LOGO 3




// Colors
const uint32_t COLOR_BLUE = 0x0099d9ea;
const uint32_t COLOR_GREEN = 0x0000FF00;

void connectToWifi();
void setupTime();
void LaunchTimer();
void flashGreen();
void transitionAnimation();
bool GetLaunchParameters();
void extractTime(const String& iso8601Time, volatile int& hour, volatile int& minute, volatile int& second);


void setup() {
    Serial.begin(115200);   // UART for Debugging

    pinMode(9, INPUT);

    // Connect to Wifi
    connectToWifi();

    // // Setup Time 
    // setupTime();

    /**
     * Add Code to get data from the Server
     */

    if(GetLaunchParameters()){
      Serial.print("Got Latest Launch Parameters");
    }

    // Setup Time 
    setupTime();

    // WiFi.disconnect();
    WiFi.disconnect(true);
    WiFi.mode(WIFI_OFF);
    

    /** ///////////////////////////////////////////////////////////////////////////////////////////////////////////////////////////
     *Setting up the LED Matrix ICs
    *//////////////////////////////////////////////////////////////////////////////////////////////////////////////////////////////
    for (int i = 0 ; i < 4 ; i++) {
      Drivers[i].interfaceInit(sdaPin, sclPin);
    }
    // Resetting the IC
    for (int i = 0 ; i < 4 ; i++) {
      Drivers[i].disableDevice();
    }
    delay(10);
    for (int i = 0 ; i < 4 ; i++) {
      Drivers[i].enableDevice();
    }
    delay(10);
    // Software enabling the IC
    for (int i = 0 ; i < 4 ; i++) {
      Drivers[i].writeRegister(Chip_Enable_Register, 0x01);
    }
    for (int i = 0 ; i < 4 ; i++) {
      Drivers[i].setDeviceInitialRegister(Max_Line_11, Mode_2, PWM_Frequency_125k);
    }
    for (int i = 0 ; i < 4 ; i++) {
      Drivers[i].setDeviceConfigReg1( SW_BLK_1us,  PWM_Scale_Exponential, PWM_PhaseShift_on,  CS_Delay_on);
      Drivers[i].setDeviceConfigReg3( Down_Deghost_Strong,  Up_Deghost_GND,  Maximum_Current_15,  Up_Deghost_En);
    }
    //////////////////////////////////////////////////////////////////////////////////////////////////////////////////////////////
    /**
     * Entering Launch Timer State by Default
     */
    menuState = LAUNCH_TIMER;

    // for (int i = 0 ; i < 4 ; i++) {
    //   Drivers[i].setBlockColour(0, 0, 255);
    //   delay(1000);
    //   Drivers[i].setBlockColour(0, 0, 0);
    //   delay(100);
    // }
    //////////////////////////////////////////////////////////////////////////////////////////////////////////////////////////////

}

void loop() {
  unsigned long currentMillis = millis();

  // Check if it is time to update NTP
  if (currentMillis - lastNTPUpdate >= NTP_UPDATE_INTERVAL) {
      configTime(gmtOffset_sec, daylightOffset_sec, ntpServer);
      lastNTPUpdate = currentMillis;
  }
  
  // Update timeinfo Struct using local RTC
  if(!getLocalTime(&timeinfo)) {
      Serial.println("Failed to obtain time");
      return;
  }

  // for (int i = 0 ; i < 4 ; i++) {
  //   Drivers[i].setBlockColour(0, 0, 100);
  // }
  // delay(1000);
  // for (int i = 0 ; i < 4 ; i++) {
  //   Drivers[i].setBlockColour(0, 0, 0);
  // }
  // delay(100);
  // // Setup Time 
  //   setupTime();
  // // Just one View for now
  // LaunchTimer();

  /**
   * TODO: Add a State machine to switch between the various views
   * 1) Launch Timer
   * 2) Injection Timer
   * 3) Time to next Pass
   * 4) Time to Sunlit/Eclipse
   * 5) Any other parameter that can be represented as a bar graph and can be fetched from the local server
   */
  switch (menuState)
  {
  case LAUNCH_TIMER:
    /* code */
    LaunchTimer();
    break;
  case INJECTION_TIMERS:
    InjectionTimers();
    break;
  case TRANSITION:
    transitionAnimation();
    break;
  default:
    break;
  }
  // if ((timeinfo.tm_hour*3600 + timeinfo.tm_min*60 + timeinfo.tm_sec) > LAUNCH_TARGET_HOUR*3600 + LAUNCH_TARGET_MIN*60 + LAUNCH_TARGET_SEC) {
  //   Launch_Done = 1;
  // }
  // InjectionTimers();

}

void connectToWifi() {
    Serial.print("Connecting to ");
    Serial.println(ssid);
    
    WiFi.begin(ssid, password);
    while (WiFi.status() != WL_CONNECTED) {
        delay(500);
        Serial.print(".");
    }
    
    Serial.println("WiFi connected");
}

void setupTime() {
    configTime(gmtOffset_sec, daylightOffset_sec, ntpServer);
    if(!getLocalTime(&timeinfo)) {
        Serial.println("Failed to obtain time");
        return;
    }
    Serial.println("Time synchronized");

    // Calculate timeRemainingToXXXXX and set Global Variables
    int currentSeconds = timeinfo.tm_hour*3600 + timeinfo.tm_min*60 + timeinfo.tm_sec;
    int targetSecondsToLaunch = LAUNCH_TARGET_HOUR*3600 + LAUNCH_TARGET_MIN*60 + LAUNCH_TARGET_SEC;

    if(targetSecondsToLaunch <= currentSeconds){
      targetSecondsToLaunch += 24*3600;         // Target is tomorrow
    }

    // timeRemainingToLaunch = targetSecondsToLaunch - currentSeconds;
    timeRemainingToLaunchSincePowerON = targetSecondsToLaunch - currentSeconds;

    // Serial.print(timeRemainingToLaunch);
}

bool GetLaunchParameters(){
  if (WiFi.status() == WL_CONNECTED) {
    HTTPClient http;
    http.begin(apiEndpoint);  // Specify API Endpoint
    int httpResponseCode = http.GET();  // Make GET Request

    if (httpResponseCode == 200) {
      String response = http.getString();
      Serial.println("Response: " + response);

      // Parse the JSON Response
      DynamicJsonDocument doc(1024);    // Adjust Size
      DeserializationError error = deserializeJson(doc, response);

      if (!error) {
        // Extract and process launch and injection times
        extractTime(doc["ff1"]["launch_time"].as<String>(), LAUNCH_TARGET_HOUR, LAUNCH_TARGET_MIN, LAUNCH_TARGET_SEC);
        extractTime(doc["ff1"]["injection_time"].as<String>(), FF1_INJECTION_TARGET_HOUR, FF1_INJECTION_TARGET_MIN, FF1_INJECTION_TARGET_SEC);
        extractTime(doc["ff2"]["injection_time"].as<String>(), FF2_INJECTION_TARGET_HOUR, FF2_INJECTION_TARGET_MIN, FF2_INJECTION_TARGET_SEC);
        extractTime(doc["ff3"]["injection_time"].as<String>(), FF3_INJECTION_TARGET_HOUR, FF3_INJECTION_TARGET_MIN, FF3_INJECTION_TARGET_SEC);

        // Print the extracted times
        Serial.printf("Launch Time: %02d:%02d:%02d\n", LAUNCH_TARGET_HOUR, LAUNCH_TARGET_MIN, LAUNCH_TARGET_SEC);
        Serial.printf("FF1 Injection Time: %02d:%02d:%02d\n", FF1_INJECTION_TARGET_HOUR, FF1_INJECTION_TARGET_MIN, FF1_INJECTION_TARGET_SEC);
        Serial.printf("FF2 Injection Time: %02d:%02d:%02d\n", FF2_INJECTION_TARGET_HOUR, FF2_INJECTION_TARGET_MIN, FF2_INJECTION_TARGET_SEC);
        Serial.printf("FF3 Injection Time: %02d:%02d:%02d\n", FF3_INJECTION_TARGET_HOUR, FF3_INJECTION_TARGET_MIN, FF3_INJECTION_TARGET_SEC);
      } else {
        Serial.println("Failed to parse JSON");
      }
    } else {
      Serial.println("HTTP GET Request failed, error: " + String(httpResponseCode));
    }
    http.end(); // Free Resources
    return 1;
  }
}

void extractTime(const String& iso8601Time, volatile int& hour, volatile int& minute, volatile int& second) {
  // Parse ISO 8601 format: "2025-01-13T13:00:00Z"
  hour = iso8601Time.substring(11, 13).toInt();  // Extract hours
  minute = iso8601Time.substring(14, 16).toInt(); // Extract minutes
  second = iso8601Time.substring(17, 19).toInt(); // Extract seconds
}

void LaunchTimer() {
  volatile float currentSeconds = timeinfo.tm_hour*3600 + timeinfo.tm_min*60 + timeinfo.tm_sec;
  volatile float targetSecondsToLaunch = LAUNCH_TARGET_HOUR*3600 + LAUNCH_TARGET_MIN*60 + LAUNCH_TARGET_SEC;
  int LaunchDone = 0;

  if(targetSecondsToLaunch <= currentSeconds){
    targetSecondsToLaunch += 24*3600;         // Target is tomorrow
  }

  volatile float timeRemainingToLaunch = targetSecondsToLaunch - currentSeconds;

  /**
   * State Transition Logic
   */
  int buttonPress = digitalRead(9);
  if (buttonPress == 0) {
    delay(50);
    buttonPress = digitalRead(9);
    if (buttonPress == 0) {
      menuState = 2;
    }
  }
  
  /**
   * TODO: Need to figure out the Launch Transition Event Handling properly. Spaghetti Logic at the moment
   */
  if (timeRemainingToLaunch <= INTIMATION_TIME && timeRemainingToLaunch > 1){
    flashGreen();
    Launch_Done = 1;
    return;
  } else if (timeRemainingToLaunch <= 0) {
    Launch_Done = 1;
  } else if (Launch_Done == 1){
    for (int i = 0 ; i < 4 ; i++) {
      Drivers[i].setBlockColour(0, 0, 255);
    }
    return;
  } else {
    // volatile float progress = (((float)timeRemainingToLaunchSincePowerON - (float)timeRemainingToLaunch)/(float)timeRemainingToLaunchSincePowerON);
    volatile float progress = (timeRemainingToLaunchSincePowerON - timeRemainingToLaunch)/timeRemainingToLaunchSincePowerON;
    Serial.print(progress);
    if (progress < 0) {
      flashGreen();
      return;
    }
    int numberOfRowsLIT = (int)(progress*24) + 1;             // Show atleast one row to start
    if (numberOfRowsLIT <= 6) {                               // Addressing only 1 Driver
      for (int i = 0; i <=numberOfRowsLIT; i++) {
        Drivers[0].lightNumberOfRows(i , 0x00007f00);
        delay(100);
      }
      delay(2000);                                            
      for (int i = 0; i <=numberOfRowsLIT; i++) {
        Drivers[0].lightNumberOfRows(i , 0x00000000);
        delay(10);
      }
      delay(1000);
      return;
      
    } else if (numberOfRowsLIT >6 && numberOfRowsLIT <=12) {  // Addressing 2nd Matrix. Fill all rows on previous Drivers
      for (int i = 0; i <=6; i++) {
        Drivers[0].lightNumberOfRows(i , 0x00007f00);
        delay(100);
      }
      for (int i = 0; i <=numberOfRowsLIT-6; i++) {
        Drivers[1].lightNumberOfRows(i , 0x00007f00);
        delay(100);
      }
      delay(2000);
      for (int i = 0; i <=6; i++) {
        Drivers[0].lightNumberOfRows(i , 0x00000000);
        // delay(100);
      }
      for (int i = 0; i <=numberOfRowsLIT-6; i++) {
        Drivers[1].lightNumberOfRows(i , 0x00000000);
        // delay(100);
      }
      delay(1000);
      return;
    } else if (numberOfRowsLIT >12 && numberOfRowsLIT <=18) {
      for (int i = 0; i <=6; i++) {
        Drivers[0].lightNumberOfRows(i , 0x00007f00);
        delay(100);
      }
      for (int i = 0; i <=6; i++) {
        Drivers[1].lightNumberOfRows(i , 0x00007f00);
        delay(100);
      }
      for (int i = 0; i <=numberOfRowsLIT-12; i++) {
        Drivers[2].lightNumberOfRows(i , 0x00007f00);
        delay(100);
      }
      delay(2000);
      for (int i = 0; i <=6; i++) {
        Drivers[0].lightNumberOfRows(i , 0x00000000);
        Drivers[1].lightNumberOfRows(i , 0x00000000);
        // delay(100);
      }
      for (int i = 0; i <=numberOfRowsLIT-12; i++) {
        Drivers[2].lightNumberOfRows(i , 0x00000000);
        // delay(100);
      }
      delay(1000);
      return;
    } else if (numberOfRowsLIT >18 && numberOfRowsLIT <=24) {
      for (int i = 0; i <=6; i++) {
        Drivers[0].lightNumberOfRows(i , 0x00007f00);
        delay(100);
      }
      for (int i = 0; i <=6; i++) {
        Drivers[1].lightNumberOfRows(i , 0x00007f00);
        delay(100);
      }
      for (int i = 0; i <=6; i++) {
        Drivers[2].lightNumberOfRows(i , 0x00007f00);
        delay(100);
      }
      for (int i = 0; i <=numberOfRowsLIT-18; i++) {
        Drivers[3].lightNumberOfRows(i , 0x00007f00);
        delay(100);
      }
      delay(2000);
      for (int i = 0; i <=6; i++) {
        Drivers[0].lightNumberOfRows(i , 0x00000000);
        Drivers[1].lightNumberOfRows(i , 0x00000000);
        Drivers[2].lightNumberOfRows(i , 0x00000000);
        // delay(100);
      }
      for (int i = 0; i <=numberOfRowsLIT-12; i++) {
        Drivers[3].lightNumberOfRows(i , 0x00000000);
        // delay(100);
      }
      delay(1000);
      return;
    }
  }

}

void flashGreen() {
  for (int i = 0 ; i < 4 ; i++) {
    Drivers[i].setBlockColour(0, 0, 255);
  }
  delay(100);
  for (int i = 0 ; i < 4 ; i++) {
    Drivers[i].setBlockColour(0, 0, 0);
  }
  delay(100);
}

void transitionAnimation() {
  while(digitalRead(9) == 0) {
    for (int i = 0; i < 4; i++) {
      Drivers[i].setBlockColour(0,255,0);         // Change to red after figuring out the setting with Yawar
    }
    delay(100);
    for (int i = 0; i < 4; i++) {
      Drivers[i].setBlockColour(0,0,0);         // Change to red after figuring out the setting with Yawar
    }
    delay(100);
  }

  // One more flash after button is released
  for (int i = 0; i < 4; i++) {
    Drivers[i].setBlockColour(0,255,0);         // Change to red after figuring out the setting with Yawar
  }
  delay(200);
  for (int i = 0; i < 4; i++) {
    Drivers[i].setBlockColour(0,0,0);         // Change to red after figuring out the setting with Yawar
  }
  delay(200);

  switch (previousMenuState)
  {
  case LAUNCH_TIMER:
    menuState = INJECTION_TIMERS;
    previousMenuState = menuState;
    break;
  
  case INJECTION_TIMERS:
    menuState = LAUNCH_TIMER;
    previousMenuState = menuState;
    break;
  
  default:
    break;
  }
}


static bool FF1InjectionDone = 0;
static bool FF2InjectionDone = 0;
static bool FF3InjectionDone = 0;


void InjectionTimers() {

  /** /////////////////////////////////////////////////////////////////////////////
   * State Transition Logic
   */ /////////////////////////////////////////////////////////////////////////////
  int buttonPress = digitalRead(9);
  if (buttonPress == 0) {
    delay(50);
    buttonPress = digitalRead(9);
    if (buttonPress == 0) {
      menuState = 2;
    }
  }
  // Very crude Debouncing. Change later if this code triggers anyone


  volatile float currentSeconds = timeinfo.tm_hour*3600 + timeinfo.tm_min*60 + timeinfo.tm_sec;
  static float LaunchTimeInSeconds = LAUNCH_TARGET_HOUR*3600 + LAUNCH_TARGET_MIN*60 + LAUNCH_TARGET_SEC;

  

  // FF1 Injection Parameters
  volatile float FF1TargetSecondsToSeparate = FF1_INJECTION_TARGET_HOUR*3600 + FF1_INJECTION_TARGET_MIN*60 + FF1_INJECTION_TARGET_SEC;
  if(FF1TargetSecondsToSeparate <= currentSeconds){
    FF1TargetSecondsToSeparate += 24*3600;         // Target is tomorrow
  }

  // FF2 Injection Parameters
  volatile float FF2TargetSecondsToSeparate = FF2_INJECTION_TARGET_HOUR*3600 + FF2_INJECTION_TARGET_MIN*60 + FF2_INJECTION_TARGET_SEC;
  if(FF2TargetSecondsToSeparate <= currentSeconds){
    FF2TargetSecondsToSeparate += 24*3600;         // Target is tomorrow
  }

  // FF3 Injection Parameters
  volatile float FF3TargetSecondsToSeparate = FF3_INJECTION_TARGET_HOUR*3600 + FF3_INJECTION_TARGET_MIN*60 + FF3_INJECTION_TARGET_SEC;
  if(FF3TargetSecondsToSeparate <= currentSeconds){
    FF3TargetSecondsToSeparate += 24*3600;         // Target is tomorrow
  }

  

  // Check if Launch is done
  if (Launch_Done == 0) {
    // Display some other colour on all Drivers till Launch is done
    for (int i = 0 ; i < 4 ; i++) {
      Drivers[i].setBlockColour(0, 100, 80);
    }
    delay(200);
    for (int i = 0 ; i < 4 ; i++) {
      Drivers[i].setBlockColour(0, 0, 0);
    }
  } else if (Launch_Done == 1) {
    // Start Injection Progress View after Launch_Done is set by LaunchTimer() or some logic in loop()

    // FF1 Display
    volatile float timeRemainingToInjectFF1 = FF1TargetSecondsToSeparate - currentSeconds;
    if (timeRemainingToInjectFF1 <= INJECTION_INTIMATION_TIME && timeRemainingToInjectFF1 > 1) {    // Indicator for the FF1 Injection Alert
      // Flash on Driver[3]
      Drivers[3].setBlockColour(0,0,255);
      delay(100);
      Drivers[3].setBlockColour(0,0,0);
      delay(100);
    } else if (timeRemainingToInjectFF1 == 0) {
      FF1InjectionDone = 1;
    } else if (FF1InjectionDone == 1) {
      Drivers[3].setBlockColour(0,100,80);
    } else {
      volatile float progressFF1 = ((FF1TargetSecondsToSeparate - LaunchTimeInSeconds) - timeRemainingToInjectFF1)/ (FF1TargetSecondsToSeparate - LaunchTimeInSeconds);
      if (progressFF1 < 0) {
        Drivers[3].setBlockColour(0, 0, 30);                                                       // Change to Red later
        return;
      }
      uint8_t numberOfRowsToLightFF1 = (uint8_t)(progressFF1 * 6) + 1;
      Drivers[3].lightNumberOfRows(numberOfRowsToLightFF1, 0x00007f00);
    }

    // FF2 Display
    volatile float timeRemainingToInjectFF2 = FF2TargetSecondsToSeparate - currentSeconds;
    if (timeRemainingToInjectFF2 <= INJECTION_INTIMATION_TIME && timeRemainingToInjectFF2 > 1) {    // Indicator for the FF1 Injection Alert
      // Flash on Driver[2]
      Drivers[2].setBlockColour(0,0,255);
      delay(100);
      Drivers[2].setBlockColour(0,0,0);
      delay(100);
    } else if (timeRemainingToInjectFF2 == 0) {
      FF2InjectionDone = 1;
    } else if (FF2InjectionDone == 1) {
      Drivers[2].setBlockColour(0,100,80);
    } else {
      volatile float progressFF2 = ((FF2TargetSecondsToSeparate - LaunchTimeInSeconds) - timeRemainingToInjectFF2)/ (FF2TargetSecondsToSeparate - LaunchTimeInSeconds);
      if (progressFF2 < 0) {
        Drivers[2].setBlockColour(0, 0, 30);                                                       // Change to Red later
        return;
      }
      uint8_t numberOfRowsToLightFF2 = (uint8_t)(progressFF2 * 6) + 1;
      Drivers[2].lightNumberOfRows(numberOfRowsToLightFF2, 0x00007f00);
    }

    // FF3 Display
    volatile float timeRemainingToInjectFF3 = FF3TargetSecondsToSeparate - currentSeconds;
    if (timeRemainingToInjectFF3 <= INJECTION_INTIMATION_TIME && timeRemainingToInjectFF3 > 1) {    // Indicator for the FF1 Injection Alert
      // Flash on Driver[1]
      Drivers[1].setBlockColour(0,0,255);
      delay(100);
      Drivers[1].setBlockColour(0,0,0);
      delay(100);
    } else if (timeRemainingToInjectFF3 == 0) {
      FF3InjectionDone = 1;
    } else if (FF3InjectionDone == 1) {
      Drivers[1].setBlockColour(0,100,80);
    } else {
      volatile float progressFF3 = ((FF3TargetSecondsToSeparate - LaunchTimeInSeconds) - timeRemainingToInjectFF3)/ (FF3TargetSecondsToSeparate - LaunchTimeInSeconds);
      if (progressFF3 < 0) {
        Drivers[1].setBlockColour(0, 0, 30);                                                       // Change to Red later
        return;
      }
      uint8_t numberOfRowsToLightFF3 = (uint8_t)(progressFF3 * 6) + 1;
      Drivers[1].lightNumberOfRows(numberOfRowsToLightFF3, 0x00007f00);
    }
  }
}

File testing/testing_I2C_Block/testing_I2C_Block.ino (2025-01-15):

#include "LP586x_I2C.h"

#include "Wire.h"
#include <stdint.h>

#define SLAVE_ADDRESS 0x10

#define ENABLE_PIN 0x01
#define SYNC_PIN 0x00

#define sdaPin 0x05
#define sclPin 0x04

/***************************************************************************//**
 *Register Address
 ******************************************************************************/
/* Device Configuration Register Address*/
#define Chip_Enable_Register               0x000
#define Device_Initial_Register            0x001
#define Device_Configuration_1_Register    0x002
#define Device_Configuration_2_Register    0x003
#define Device_Configuration_3_Register    0x004

#define LED_Group_Selection_Register_start 0x00C //Register address from 0x009 to 0x042
#define LED_Dot_Onoff_Register_start       0x043 //Register address from 0x043 to 0x063

/* Current Configuration Register Address */
#define Color_Group_R_Current_Register     0x009
#define Color_Group_G_Current_Register     0x00A
#define Color_Group_B_Current_Register     0x00B
#define LED_Dot_Current_Register_Start     0x100 //Register address from 0x100 to 0x1C5

/* Brightness Configuration Register Address */
#define Master_Brightness_Register         0x005
#define Group_1_Brightness_Register        0x006
#define Group_2_Brightness_Register        0x007
#define Group_3_Brightness_Register        0x008
#define LED_Dot_Brightness_Register_Start  0x200 //Register address from 0x200 to 0x2C5 (8-bit) Or to 0x38B (16-bit)

/* Fault Register Address*/
#define Fault_State_Register               0x064
#define LED_Dot_LOD_Register_start         0x065 //Register address from 0x065 to 0x085
#define LED_Dot_LSD_Register_start         0x086 //Register address from 0x086 to 0x0A6

/* Reset Register Address*/
#define LOD_Clear_Register                 0x0A7
#define LSD_Clear_Register                 0x0A8
#define Reset_Register                     0x0A9

/***************************************************************************//**
 *Register Value
 ******************************************************************************/
#define Chip_Disable                       0x00
#define Chip_Enable                        0x01

#define LOD_Clear_En                       0xff
#define LSD_Clear_En                       0xff
#define Reset_En                           0xff

LP586X_I2C test_driver(ENABLE_PIN, SYNC_PIN);

void setup() {
    Serial.begin(115200);
    test_driver.begin(sdaPin, sclPin);

    // Resetting the IC
    test_driver.disableDevice();
    delay(10);
    test_driver.enableDevice();
    delay(10);

    // Writing to a register and software enabling the IC
    test_driver.setSlave(SLAVE_ADDRESS, Chip_Enable_Register);
    test_driver.writeRegister(Chip_Enable_Register, 0x01);

    uint8_t data = test_driver.readRegister(Chip_Enable_Register);
    Serial.print("Register Value: ");
    Serial.print(data);

    // Reading Default Value of Device_Initial_Register
    data =test_driver.readRegister(Device_Initial_Register);
    Serial.print("Register Value: ");
    Serial.print(data);
}

void loop() {
    // Reading Default Value of Device_Initial_Register
    int data =test_driver.readRegister(Device_Initial_Register);
    Serial.print("Register Value: ");
    Serial.print(data);
    delay(1000);
}
